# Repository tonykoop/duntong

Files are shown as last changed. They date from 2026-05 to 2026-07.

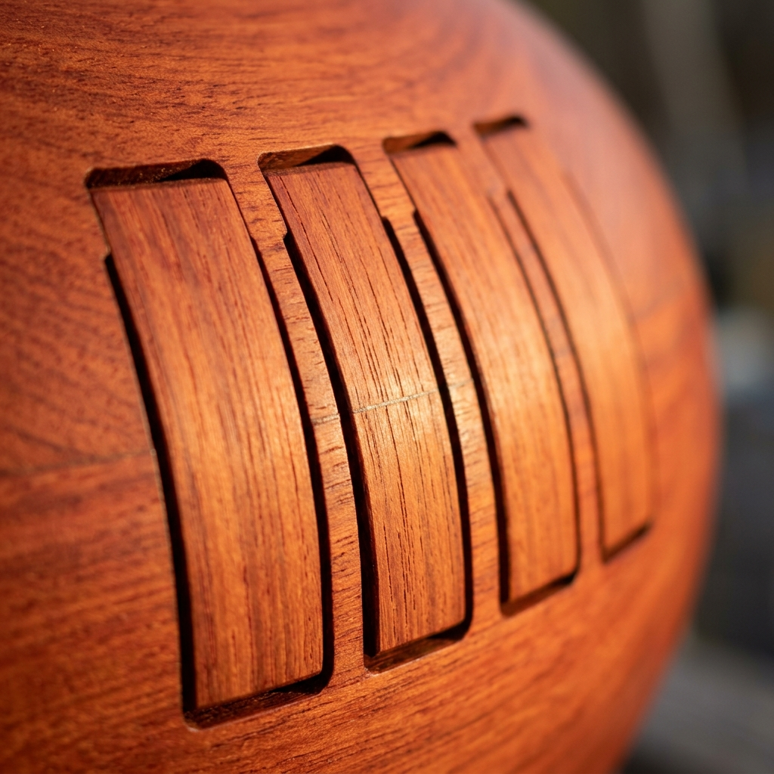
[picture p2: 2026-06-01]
images/macro/tongue-ring.png

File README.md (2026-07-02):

# Duntong - Original Cylindrical Tongue Drum

> Tony Koop's original hybrid instrument concept: a dundun-inspired cylindrical drum body with tuned wooden tongue-drum voices cut around the shell.

**Status:** L2 V5 build-packet candidate

## What This Is

The duntong is an original instrument design by Tony Koop. It combines the social, cylindrical playing form of a hand drum with the melodic tuning logic of a wooden tongue drum. Instead of cutting tongues into a flat box lid, the duntong places cantilever tongues around a round shell so the instrument can be played from multiple sides.

The current design table defines two prototype sizes:

1. **Handheld:** 6 in OD x 9 in long, C5-root pentatonic minor, 0.375 in tongue wall.
2. **Medium:** 12 in OD x 16 in long, C4-root pentatonic minor, 0.5 in tongue wall.

The V1 build target is the medium stave-cylinder prototype with a single ring of eight tongues around the equator. The workbook also preserves sealed, ported, and drumhead end variants so the instrument can be tested as a melodic tongue drum, a resonant ported body, and a true dundun/tongue hybrid.

## Why It Is Interesting

Most wooden tongue drums are rectangular boxes. Most dunduns are membrane drums. The duntong asks a neat acoustics question: can a round wooden drum body carry tuned cantilever tongues while still behaving like a hand-drum shell?

The current model treats the tongues as fixed-free cantilever beams:

```text
f = K * t / L^2
```

The cylinder cavity is treated as secondary coupling, not as the main pitch source. The first prototype should measure how much the curved wall, stave glue lines, end condition, and cavity resonance shift the tongue predictions.

## Repository Map

```text
duntong/
├── README.md
├── design.md
├── duntong-design-table.xlsx
├── family-spec.csv
├── bom.csv
├── sourcing.csv
├── cut-list.csv
├── validation.csv
├── assembly-manual.md
├── supplier-rfq.md
├── visual-bom-brief.md
├── drawing-brief.md
├── risks.md
├── photo-shotlist.md
├── cad/
├── cnc/
├── data/
├── drawings/
├── images/
├── site/
├── wolfram/
└── evolution/
```

## Current Status

L2 V5 build-packet candidate; not build-ready. The repo has
workbook-derived dimensions, a parametric OpenSCAD master-layout starter,
review SVG drawings, CNC planning notes, and print/capstone outputs. It does
not yet contain measured prototype data, SolidWorks-native CAD, DXF exports,
MCP-generated renders, or shop-validated CAM.

| Area | Status |
|---|---|
| Original concept and workbook | Done |
| Guided v4.2 intake | Done |
| Build packet docs | Drafted for V1 review; not build-ready |
| Drawings | SVG review drawings included; no DXF fabrication export yet |
| CNC/CAM | Pre-CAM operation plan only; no G-code |
| OpenSCAD | Parametric master-layout starter; not production CAM |
| SolidWorks | MasterLayout handoff files included; no native SolidWorks part yet |
| Visual authority | `visual-output-register.csv` records design-table/CAD authority and review-only previews |
| Explorer | Root `explorer.html` added for packet review |
| Wolfram | Readable `.wl` source included; source-only, not executed |
| Prototype data | Forthcoming |
| Evolution intake | Stage 0 intake complete (`evolution/`); Gate A not run |

## Authority And Unknowns

- Fabrication authority is limited to workbook/design-table-derived starter
  values in `duntong-design-table.xlsx`, `cad/design-table-inputs.csv`, and
  `cad/sw-global-variables.csv`.
- `cad/duntong_master.scad` is a parametric master-layout starter. It is useful
  for review, STL experiments, and downstream CAD translation, but it is not
  shop-validated production geometry.
- SVG files in `drawings/` are review previews. They do not replace a checked
  DXF, native CAD drawing, or measured template.
- Padauk material constants, curved-shell tongue behavior, end-condition
  coupling, drumhead hardware, D minor retuning, fixture clearances, feeds and
  speeds, and all prototype tuning data remain measurement-required.

## Sister Repos

- [tongue-drum](https://github.com/tonykoop/tongue-drum) for cantilever tongue physics and the DoE tuning pattern.
- [dundun](https://github.com/tonykoop/dundun) for the drum-family inspiration.
- [djembe](https://github.com/tonykoop/djembe) and [ashiko-drum-workshop](https://github.com/tonykoop/ashiko-drum-workshop) for segmented/stave drum construction references.

## License

[CC BY 4.0](LICENSE) - see LICENSE for details.

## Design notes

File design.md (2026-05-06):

# Duntong Build Design

## Project Intent

The duntong is Tony Koop's original cylindrical tongue drum concept. It combines a dundun-like round body and optional drumhead/ported ends with wooden tongue drum voices cut directly into the shell wall.

The first build should answer three practical questions:

1. Can a cylindrical stave shell hold predictable cantilever tongue pitches?
2. Which end configuration gives the best musical balance: sealed, ported, or drumheaded?
3. Can the V1 be manufactured safely with Tony's available home-shop and Maker Nexus workflows before SolidWorks CAM exists?

Mode A repo shape is used here: this is a single-instrument repository, so files live at the repo root and in conventional folders.

## Design Intake

| Field | Value |
|---|---|
| Instrument ID | DNT-001 |
| Instrument type | Duntong |
| Family | Cylindrical tongue drum / drum-skin hybrid |
| Inventor | Tony Koop, 2026 |
| Workbook | `duntong-design-table.xlsx`, sheet `Duntong` |
| Reference workbook | `Musical Instruments V2.xlsx`, sheet `Duntong` |
| Done-bar reference | `tonykoop/tongue-drum` for tongue physics; `tonykoop/djembe`, `tonykoop/conga`, and `tonykoop/ashiko-drum-workshop` for segmented/stave construction |
| V1 recommendation | Medium stave cylinder, single-ring tongue layout, sealed or goatskin end option |
| Current scale baseline | C minor pentatonic from the workbook |
| Alternate scale request | D minor pentatonic remains TBD until the workbook row is updated |
| Primary material | Padauk in the workbook; cherry or maple alternate TBD |

Guided intake outputs are in `data/design-intake.json` and `data/design-input-row.csv`.

## Governing Model

### Tongues

The primary pitch model is a fixed-free cantilever beam:

```text
f = K * t / L^2
L = sqrt(K * t / f)
```

Where:

- `f` is tongue fundamental frequency in Hz.
- `K` is the material-specific imperial cantilever constant from the tongue-drum material library.
- `t` is the shell wall thickness in inches. This is also the tongue thickness.
- `L` is tongue length in inches.

For the workbook baseline, `K = 24438` for Padauk. The model assumes the tongue behaves like a flat cantilever. The workbook flags curvature as acceptable when tongue width divided by cylinder OD is less than or equal to 0.20. The handheld ratio is 1.0 / 6.0 = 0.167. The medium ratio is 1.5 / 12.0 = 0.125. Both are inside the first-pass range, but the curved shell may still raise pitch by about 2-5 percent and must be measured.

### Body And End Coupling

The cylinder body is secondary coupling, not the main pitch source. Four end conditions are preserved as design variants:

| Option | End condition | First-pass model | Musical character |
|---|---|---|---|
| A | Both ends solid | Helmholtz-like cavity using tongue slits as neck openings | Warm, focused sustain |
| B | One port, one solid | Stopped pipe approximation | Deeper bass projection |
| C | Two ports | Open pipe approximation | Brighter projection |
| D | One or both drumheads | Membrane plus cantilever hybrid | Closest to dundun inspiration |

Important guard rule: the NAF K2 bore correction does not apply to this instrument. Only cantilever beam K constants are used for tongue pitch. Helmholtz/stopped/open-pipe equations are exploration and validation targets for the body, not corrections to tongue length.

### Worked Medium Example

For the medium prototype:

```text
OD = 12.000 in
length = 16.000 in
wall/tongue thickness = 0.500 in
tongue width = 1.500 in
slit width = 0.125 in
K = 24438
root MIDI = 60 (C4)
```

The C4 tongue prediction is:

```text
L = sqrt(24438 * 0.5 / 261.63) = 6.834 in
```

The medium shell circumference is `pi * 12 = 37.699 in`, allowing about 23 tongue-width-plus-slit slots. The requested 8 tongues fit.

Using the workbook formula for sealed-body slit-area coupling:

```text
slit area = 8 * (0.125 * 1.5 + 2 * 0.125 * 3.0) = 7.5 in^2
internal volume = pi * (11 / 2)^2 * 16 = 1520.5 in^3
effective neck length = 0.5 in
f_H = 13552 / (2*pi) * sqrt(7.5 / (1520.5 * 0.5)) = about 214 Hz
```

The workbook prose note also mentions 135 Hz for medium sealed coupling. That appears to be a stale or alternate-geometry note; keep it visible as a validation question rather than treating either value as proven.

## Family / Variant Targets

| Variant | OD (in) | Length (in) | Wall (in) | Root | Tongues | Construction target |
|---|---:|---:|---:|---|---:|---|
| DNT-HANDHELD | 6.000 | 9.000 | 0.375 | C5 | 8 | Split-blank or stave prototype |
| DNT-MEDIUM | 12.000 | 16.000 | 0.500 | C4 | 8 | V1 stave cylinder |

Medium predicted tongue table:

| # | Note | MIDI | Target Hz | Predicted L (in) |
|---:|---|---:|---:|---:|
| 1 | C4 | 60 | 261.63 | 6.834 |
| 2 | Eb4 | 63 | 311.13 | 6.267 |
| 3 | F4 | 65 | 349.23 | 5.915 |
| 4 | G4 | 67 | 392.00 | 5.583 |
| 5 | Ab4 | 68 | 415.30 | 5.424 |
| 6 | Bb4 | 70 | 466.16 | 5.120 |
| 7 | C5 | 72 | 523.25 | 4.832 |
| 8 | Eb5 | 75 | 622.25 | 4.431 |

## Hardware Alignment

The V1 build is a stave-cylinder shell with CNC-cut tongue slits. The CNC plan is pre-CAM only; feeds, speeds, hold-down, and simulation must be set at the actual machine.

| Operation | Tooling | Fixture / datum | Notes |
|---|---|---|---|
| Rip staves | Table saw, miter sled | Long edge datum, 15 deg miter for 12 staves | Cut extra staves for tuning and destructive tests |
| Thickness staves | Planer / drum sander | Outside face A | Tongue pitch depends directly on final wall thickness |
| Glue cylinder | Band clamps or hose clamps | Shell axis datum A | Glue in two half-shells, then join halves |
| True shell | Lathe | Shell axis between centers/chuck | Final wall is tuning-critical |
| End cap or drumhead prep | Lathe, band saw, drill press | End plane datum B/C | Preserve sealed, ported, and drumhead variants |
| Tongue layout | 1:1 wrap template or SolidWorks unwrap | Shell axis A, equator plane D, index zero E | Single ring around equator for V1 |
| Tongue cuts | CNC router, 1/8 in upcut spiral | V-block cradle, rotary indexing, shell axis A | Start tongues about 5 percent long/flat for tuning trim |
| Tuning | Files, Dremel, tuner | Tongue root and tip marks | Shorten tip to raise pitch; thin near base to lower pitch |

## SolidWorks MasterLayout Plan

Do not fake SolidWorks files. This repo includes a real handoff:

- `cad/SolidWorks-MasterLayout-Plan.md`
- `cad/design-table-inputs.csv`
- `cad/sw-global-variables.csv`

The MasterLayout should own shell OD/ID/length, wall thickness, stave count, miter angle, tongue count, tongue lengths, slit width, tongue band position, end cap variant, port diameter, trim allowance, and registration datums. It should also include an unwrap or wrap-template drawing for V1 CNC layout.

## Open Assumptions

| Assumption | Status | Test |
|---|---|---|
| Padauk K = 24438 applies to curved shell tongues | First-order only | Measure struck pitch before and after slit tuning |
| Curvature ratio below 0.20 keeps flat-beam formula usable | First-order only | Compare predicted vs measured cents error on all eight tongues |
| Medium sealed-body coupling is near 214 Hz by current formula | Formula result | Verify against Excel cached value and measured cavity tap/impulse response |
| Workbook prose note of 135 Hz body resonance is stale or alternate geometry | TBD | Recalculate in Excel and Wolfram after dimensions are frozen |
| Single-ring layout is playable by one or two players | TBD | Mock hand reach on a 12 in diameter cylinder before CNC |
| Goatskin end option is the "true duntong" expression | Design intent | Build sealed, ported, and goatskin variants for comparison |

## Validation Plan

1. Build a scrap tongue coupon at the same wall thickness and grain orientation.
2. Cut one reference C4 tongue 5 percent long and tune upward to target.
3. Record before/after frequency, humidity, temperature, and material thickness.
4. Build the medium shell and cut the eight tongues from longest to shortest.
5. Measure every tongue after rough cut, after tuning, and after finish.
6. Test sealed, one-port, and goatskin end configurations with the same tongue set where practical.
7. Update `validation.csv` and feed measured data back through the empirical-learning loop once a prototype exists.

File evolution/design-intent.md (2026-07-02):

# Design Intent — duntong rev A

- Master CAD: `cad/duntong_master.scad` (sha256: 723e69e6e639454bb9617963085709aae8129c8bf647d1cce9ca808ccdad349c), driven by `duntong-design-table.xlsx` (sha256: f86e424c1b98947c1ae340889d75ffa5f2e7d94e46fb72afa1dfbccc727afe02)
- Function: A cylindrical stave-shell drum body that carries tuned cantilever wooden tongues cut around its wall (V1 target: medium size, 12 in OD x 16 in long, single ring of eight tongues, C4-root pentatonic minor, sealed end baseline). The tongues are the primary pitch source (fixed-free cantilever, `f = K * t / L^2`, Padauk `K = 24438`); the cylinder cavity and end condition (sealed / one-port / two-port / drumhead) are secondary coupling under test. Handheld variant (6 in OD x 9 in long, C5-root) is preserved as a parametric alternate.
- Environment: hand-played percussion/melodic instrument; struck tongues carry cyclic fatigue load at stave glue lines; solid-wood shell and tongues move with humidity; optional goatskin head carries static rope-tension load.
- Target qty: 1 (prototype). Deadline: TBD. Budget/unit ceiling: TBD.

## Critical dimensions (carry tolerances)

| Feature | Nominal | Tolerance | Why critical | Source |
| --- | --- | --- | --- | --- |
| Shell OD (medium) | 12.000 in | scrap-coupon Hz check before shell cut | sets cavity coupling + tongue width/OD curvature ratio | design-table-inputs.csv row DNT-MEDIUM-SEALED |
| Wall thickness (= tongue thickness, medium) | 0.500 in | ±5% cents error tolerance (validation.csv) | directly sets tongue frequency via `f = K*t/L^2` | design-table-inputs.csv / validation.csv tolerance_cents=5 |
| Tongue length per note (medium, e.g. C4) | 6.834 in (predicted) | measured vs. target Hz, 5 cents tolerance | intonation | validation.csv V-001, cantilever formula |
| Tongue width | 1.500 in (medium) / 1.000 in (handheld) | width/OD ≤ 0.20 (curvature validity limit) | keeps flat-cantilever model valid; curved shell may still shift pitch 2-5% (measurement-required) | design.md Governing Model |
| Stave count / miter angle | 12 staves, 15.000 deg miter | glue-line placement vs. tongue centerlines | tongue must not cross a glue line (risks.md, High severity) | cad/design-table-inputs.csv |
| Root note (medium) | MIDI 60 (C4) | design-table row change required to alter | sets whole pentatonic layout | design-table-inputs.csv root_midi |
| Body cavity response (sealed, medium) | 214.23 Hz (first-pass) | ±20 cents tolerance, verify vs. Excel + impulse response | secondary coupling could shift measured tongue Hz | validation.csv V-009 |
| Port diameter (ported variant) | 3.000 in | measurement-required if Config B/C built | stopped/open-pipe body tuning | design-table-inputs.csv port_diameter_in |

## Incidental (free for DFM)

- End-cap cosmetic profile, stave grain/figure selection (beyond stated material), rubber-foot/cradle-stand styling, finish sheen, note-position labeling/inlay.

## Must-nots (DFM may never violate)

- Tongue centerlines must not cross stave glue lines without a validated split-blank or wider non-vibrating bridge (risks.md, Structural, Severity: High — human decision required before cutting).
- Do not substitute tonewood species without updating the workbook `K` constant and cutting a validated coupon first (risks.md, Supply).
- Do not finish tuned tongues with the standard schedule before measuring before/after Hz and damping on a coupon (risks.md, Fit/Finish).
- Tongue width/OD ratio must stay ≤ 0.20 (design.md validity boundary) or the flat-cantilever model is no longer applicable without a re-derived curved-shell correction.

## Material intent

- Preferred: Padauk staves and end caps (or matching hardwood) per bom.csv B-001/B-002; goatskin/calfskin head optional for the drumhead-hybrid end variant (B-004).
- Acceptable subs: cherry or hard maple for body/tongues if the workbook `K` constant is updated first (bom.csv substitute_rule); synthetic head as an alternate to goatskin.
- Forbidden: none recorded.

## Stage status

Stage 0 intake complete 2026-07-01. Gate A (Alpha shop compile) NOT yet run — no concessions logged, nothing presented as shippable.

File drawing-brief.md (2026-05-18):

# Drawing Brief

## Drawing Set

The current SVG drawing set is review-grade and should be replaced or extended by SolidWorks drawings before cutting expensive stock.
Visual authority for the current packet is tracked in
`visual-output-register.csv`. The existing SVG files are derived review
previews, not DXF/CAD fabrication authority.

| Drawing | Purpose |
|---|---|
| `drawings/body-overview.svg` | Overall medium and handheld envelopes, major datums, V1 build target |
| `drawings/tongue-layout.svg` | Single-ring tongue schedule, note order, tongue lengths, wrap-template concept |
| `drawings/end-config-options.svg` | Sealed, ported, open/open, and drumhead end variants |
| `drawings/section-view.svg` | Cross-section of stave shell, wall/tongue thickness, end cap, V-block fixture concept |

## Drawing Standards

Each drawing must preserve:

- Title block with instrument, part, units, revision, date, and source workbook.
- Datums: shell axis A, left end B, right end C, equator plane D, index zero E.
- Critical dimensions: OD, ID, length, wall/tongue thickness, tongue length, tongue width, slit width, port diameter, and end cap rabbet.
- Default tolerance block: +/- 0.005 in for tongue length/thickness, +/- 0.030 in for noncritical wood body features unless CAD says otherwise.
- Material notes: Padauk baseline, alternate species require K update.
- Operation notes: no G-code; V-block or rotary indexing required for cylindrical tongue cuts.

## CAD Handoff

SolidWorks should create:

1. MasterLayout part with global variables from `cad/sw-global-variables.csv`.
2. Configuration table for handheld and medium variants.
3. Cylindrical unwrap sketch for the single-ring tongue layout.
4. Optional end-cap configurations: sealed, ported, drumhead.
5. Drawing sheets exported to PDF/SVG before CAM.

## Missing V5 Visual Gates

- Export checked DXF plates from native CAD or an Illustrator-reviewed vector
  master before marking the drawing set shop-ready.
- Replace review SVG previews with derived previews that name the governing
  CAD/DXF/design-table source.
- Add Blender/Photoshop/image-generation outputs only after logging their
  source artifacts and keeping them concept/support-only unless derived from
  fabrication authority.

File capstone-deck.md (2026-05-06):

# Duntong Original Cylindrical Tongue Drum
- Musical instrument documentation capstone
- Build packet: duntong
- Generated: 2026-05-05

---

# Project Intent
- The duntong is Tony Koop's original cylindrical tongue drum concept. It combines a dundun-like round body and optional drumhead/ported ends with wooden tongue drum voices cut directly into the shell wall.

_Speaker notes:_ Read design.md before committing to dimensions or sourcing decisions.

---

# Physics Model
- ### Tongues

```
f = K * t / L^2
L = sqrt(K * t / f)
```

```
OD = 12.000 in
length = 16.000 in
wall/tongue thickness = 0.500 in
tongue width = 1.500 in
slit width = 0.125 in
K = 24438
root MIDI = 60 (C4)
```

```
L = sqrt(24438 * 0.5 / 261.63) = 6.834 in
```

```
slit area = 8 * (0.125 * 1.5 + 2 * 0.125 * 3.0) = 7.5 in^2
internal volume = pi * (11 / 2)^2 * 16 = 1520.5 in^3
effective neck length = 0.5 in
f_H = 13552 / (2*pi) * sqrt(7.5 / (1520.5 * 0.5)) = about 214 Hz
```

_Speaker notes:_ Governing equations extracted verbatim from design.md. Apply empirical corrections (NAF K2, scale offsets) only where the model permits — see references/acoustic-models.md.

---

# Hardware Alignment
- The V1 build is a stave-cylinder shell with CNC-cut tongue slits. The CNC plan is pre-CAM only; feeds, speeds, hold-down, and simulation must be set at the actual machine.

| Operation | Tooling | Fixture / datum | Notes |
| --- | --- | --- | --- |
| Rip staves | Table saw, miter sled | Long edge datum, 15 deg miter for 12 staves | Cut extra staves for tuning and destructive tests |
| Thickness staves | Planer / drum sander | Outside face A | Tongue pitch depends directly on final wall thickness |
| Glue cylinder | Band clamps or hose clamps | Shell axis datum A | Glue in two half-shells, then join halves |
| True shell | Lathe | Shell axis between centers/chuck | Final wall is tuning-critical |
| End cap or drumhead prep | Lathe, band saw, drill press | End plane datum B/C | Preserve sealed, ported, and drumhead variants |
| Tongue layout | 1:1 wrap template or SolidWorks unwrap | Shell axis A, equator plane D, index zero E | Single ring around equator for V1 |
| Tongue cuts | CNC router, 1/8 in upcut spiral | V-block cradle, rotary indexing, shell axis A | Start tongues about 5 percent long/flat for tuning trim |
| Tuning | Files, Dremel, tuner | Tongue root and tip marks | Shorten tip to raise pitch; thin near base to lower pitch |

_Speaker notes:_ Identifies which shop pipeline(s) this instrument lives in: Bambu+kiln slip-cast, 40W laser flat-pack, CNC+lathe, segmented turning, drum-skin work, or hybrid combinations.

---

# How To Use This Packet
- Start with design.md for intent and assumptions.
- Use bom.csv, sourcing.csv, and cut-list.csv before buying or cutting.
- Use drawing-brief.md and CAD/CNC folders before machining.
- Print the packet for shopping, shop work, and validation.

---

# File Map
- design.md: Project intent, catalog metadata, assumptions, and validation plan.
- bom.csv: Starter bill of materials with part categories, quantities, drawing refs, and notes.
- sourcing.csv: Supplier/search tracker with specs, price/date fields, lead time, substitutes, and risks.
- cut-list.csv: Rough/final stock sizes, material, grain/orientation, operations, yield, and offcuts.
- drawing-brief.md: Manufacturing drawing and technical product sketch brief.
- assembly-manual.md: Shop-facing sequence, tools, fixtures, safety, tuning, finishing, and maintenance notes.
- validation.csv: Target/measured values, tolerance, environment, result, and tuning/build action log.
- supplier-rfq.md: Supplier email/request-for-quote starter.

---

# Family Spec

| member_id | target_hz | target_note | scale_label | predicted_length_in | predicted_width_in | predicted_height_in | predicted_volume_cuin | wood_species | k_constant | k2_correction | outer_diameter_in | inner_diameter_in | wall_thickness_in | tongue_count | slit_width_in | construction_method | notes |
| --- | --- | --- | --- | --- | --- | --- | --- | --- | --- | --- | --- | --- | --- | --- | --- | --- | --- |
| DNT-HANDHELD | 523.25 | C5 | C minor pentatonic | 9.000 | 6.000 | 6.000 | 194.83 | Padauk | 24438 | 0 | 6.000 | 5.250 | 0.375 | 8 | 0.125 | split-blank or stave | Handheld proof of concept; workbook root MIDI 72 |
| DNT-MEDIUM | 261.63 | C4 | C minor pentatonic | 16.000 | 12.000 | 12.000 | 1520.53 | Padauk | 24438 | 0 | 12.000 | 11.000 | 0.500 | 8 | 0.125 | stave cylinder | V1 build target; medium floor/table instrument |

_Speaker notes:_ Sizes scale via the master scale factor; tuning targets are first-order Helmholtz/cantilever predictions to be empirically corrected per prototype.

---

# Build Workflow
- Design and assumptions
- Source materials and hardware
- Prepare stock, fixtures, and CNC/laser/lathe setup
- Assemble, tune, finish, and validate

---

# Sourcing And BOM
- BOM gives part categories and drawing references.
- Sourcing tracks search terms, supplier candidates, price/date, lead time, substitutions.
- Visual BOM brief turns the parts list into a presentation-ready image board.

---

# Shop Packet
- Cut list for lumber/sheet/blank planning.
- Assembly manual for away-from-keyboard work.
- Validation sheet for measured dimensions, tuning, pass/fail checks.

---

# Drawings, CAD, CNC
- drawing-brief.md defines required views, dimensions, datums, sketch intent.
- cad/ holds models and design tables.
- cnc/ holds CAM, toolpaths, setup sheets, dry-run notes.
- drawings/ holds PDFs, SVGs, DXFs, drawing exports.






---

# Images And Screenshots
- Add hero render/photo, visual BOM, shop screenshots, drawing previews, validation photos in images/.

---

# Validation Plan
- A4 = 440 Hz reference check.
- Tuning targets logged in validation.csv.
- Critical dimensions verified against design sheet and CAD.
- Photos and revision notes after each major step.

---

# Open Risks / Decisions
- TBDs in design sheet and BOM.
- Supplier price/availability not yet verified.
- Generated images marked as concept placeholders.
- Empirical corrections await measured prototype data.

---

# Next Actions
- Replace TBDs with measured/source-backed values.
- Verify live supplier price and availability before buying.
- Export final drawings and visual BOM images.
- Regenerate this deck and print packet after final edits.

---

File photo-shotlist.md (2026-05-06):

# Photo Shotlist

This follows `instrument-maker/docs/photo-pipeline.md`. No owned duntong hero photo exists yet, so the README and site should say photos forthcoming rather than link broken images.

## File Naming

Use:

```text
images/00-hero-duntong-medium-finished.jpg
images/01-workbook-design-table.jpg
images/02-stave-stock-layout.jpg
images/03-stave-glue-up.jpg
images/04-turned-cylinder-shell.jpg
images/05-wrap-template-on-shell.jpg
images/06-vblock-cnc-setup.jpg
images/07-tongue-slit-cutting.jpg
images/08-tuning-with-tuner.jpg
images/09-end-config-comparison.jpg
images/10-finished-detail.jpg
```

## Required Shots

| Shot | Purpose | Status |
|---|---|---|
| Hero finished instrument | README/site hero | Forthcoming |
| Workbook/source table | Shows parametric design source | Forthcoming |
| Stave stock | Documents grain and material | Forthcoming |
| Stave glue-up | Shows cylindrical shell construction | Forthcoming |
| Lathe turning | Shows wall thickness control | Forthcoming |
| Wrap template | Shows cylindrical tongue layout | Forthcoming |
| V-block CNC setup | Shows safe workholding | Forthcoming |
| Tongue cutting | Shows slit operation | Forthcoming |
| Tuning | Shows validation method | Forthcoming |
| End variants | Sealed/ported/drumheaded comparison | Forthcoming |

## Rules

- Use owned photos when available.
- If generated concept images are added, label them as generated placeholders.
- Replace generated or drawing placeholders with process photos after the first prototype.
- Do not use absolute local paths in README or `site/index.html`.

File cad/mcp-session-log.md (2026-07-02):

# MCP Session Log - Duntong

Current status: no MCP sessions were run in this Round 30 conservative lane.
This log is present so future V5 work can record OpenSCAD, Blender,
Illustrator, Photoshop, image-generation, or other MCP-generated artifacts
without inventing provenance for the existing packet.

| timestamp_utc | tool | session_id | artifact | parent_artifact | authority | notes |
|---|---|---|---|---|---|---|
| 2026-05-18 | none | n/a | cad/duntong_master.scad | cad/design-table-inputs.csv | starter_layout | Existing OpenSCAD starter reviewed as packet evidence; no live MCP session used in this lane. |
| 2026-05-18 | none | n/a | drawings/*.svg | cad/design-table-inputs.csv | derived_preview | Existing SVGs are review previews and are tracked in visual-output-register.csv. |
| 2026-07-01 | claude-code (Fable 5) + OpenSCAD CLI | fable-v5-refresh-2026-07-01 | cad/duntong_master.scad | cad/design-table-inputs.csv | pending_measurement | V5 packet refresh: existing parametric master kept as-is (EXISTING MASTERS clause; not rewritten). Render check: `openscad -o /tmp/duntong-check.stl cad/duntong_master.scad`, exit 0. |
| 2026-07-01 | claude-code (Fable 5) | fable-v5-refresh-2026-07-01 | wolfram/duntong-wolfram-model.wl | cad/design-table-inputs.csv | derived_preview | Existing Wolfram cantilever/cavity model source reviewed for V5 register; source-only, not executed (wolframscript not run per V5 evidence rule). |
| 2026-07-01 | claude-code (Fable 5) | fable-v5-refresh-2026-07-01 | bom.csv, sourcing.csv, cut-list.csv, validation.csv, cad/design-table-inputs.csv | duntong-design-table.xlsx | fabrication | V5 refresh pass: tabular packet data reviewed against design-table baseline; no dimension changes made. Provenance row added to satisfy V5 fabrication-artifact logging. |

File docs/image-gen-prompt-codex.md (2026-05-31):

# Duntong Image-Gen Prompts

Concept visualization only; not fabrication authority. Do not infer tongue
lengths, shell thickness, port size, head hardware, or tuning from these
prompts.

## Hero Prompt

Photorealistic 3/4 product photograph of the Duntong, Tony Koop's original cylindrical tongue-drum concept: a medium stave-built round wooden cylinder with a single ring of eight tuned tongue shapes cut around the equator, warm Padauk, cherry, or maple wood, smooth turned ends, and an optional sealed end, ported end, or goatskin drumhead variant visible at one side. The instrument should read as a dundun-inspired body crossed with a wooden tongue drum, playable from multiple sides, with soft mallets nearby for scale. Clean studio background, soft directional lighting, 50mm lens, high detail, photorealistic.

## In-Context Prompt

Photorealistic workshop scene of the Duntong prototype being tested on a bench cradle: a player uses soft mallets to strike the tongue ring around the cylinder while another end configuration, wrap template, tuner, and CNC V-block cradle sit nearby. Natural shop light, visible stave construction, believable hand reach around the shell, and an exploratory original-instrument mood.

## Detail / Macro Prompt

Photorealistic macro close-up of the Duntong tongue band: curved-shell wooden cantilever tongues cut cleanly around a cylindrical stave body, fine slit kerfs, visible equator layout marks removed or faint, and a smooth satin finish showing grain direction across each tongue. Show the shell curvature and tongue relief clearly, with a soft mallet head entering the edge of frame. High-detail macro, shallow depth of field.

## Negative / Avoid

No text, logos, watermarks, flat box tongue drum, impossible curved slits, fake note labels, extra limbs, distorted hands, or cutaway dimensions.

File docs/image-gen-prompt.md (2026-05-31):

# Image-Gen Prompts

Concept image only; not fabrication authority. Do not include cut-ready dimensions, hole locations, or toolpaths.

## Hero Prompt

A single finished "duntong," an original cylindrical wooden tongue drum standing upright like a short barrel: a tall round drum body built from many narrow vertical Padauk staves glued into a seamless cylinder, the wood a warm reddish-orange with subtle vertical grain lines marking the stave seams, satin oil finish catching the light. Around the middle of the cylinder, encircling it like a belt, runs a single ring of eight slender wooden tongues cut directly into the curved shell wall — each tongue a long narrow rectangular cutout, fixed at one end and free at the tip, the tongues stepping shorter in sequence around the circumference to suggest a tuned melodic scale, thin dark slit gaps outlining each tongue against the body. The top end shows a recessed solid wooden end cap; the form reads as a hand-drum shell that has been turned smooth and true on a lathe. Realistic table-height scale, roughly a foot in diameter. Clean neutral studio background, soft directional studio light raking across the curved staves to show the cylinder's roundness and the relief of the cut tongues, 3/4 product-photography angle, ~50mm lens, high detail, photorealistic, no text labels.

## In-Context Prompt

Two duntong drums staged together on a warm wooden workshop bench near a window — the larger medium floor-size cylinder standing on the bench and the smaller handheld version resting beside it, both turned from reddish-orange Padauk staves with the signature ring of eight cut tongues around each shell equator. A pair of soft felt-tipped mallets and a few wood shavings rest nearby, hinting at a recently completed build. Natural side light from the window, shallow depth of field with the smaller drum softly out of focus, environmental storytelling of a maker's shop, concept visualization only, photorealistic, no text labels.

## Detail Prompt

Macro close-up of the signature tongue ring on the curved Padauk shell: three or four adjacent cantilever tongues cut into the rounded wall, each a long slender rectangle anchored at its base and free at the tip, separated from the body by a clean narrow dark slit that wraps slightly with the cylinder's curvature. Show the fine vertical grain of the reddish-orange wood, the faint glue seams between staves crossing the tongues, the crisp routed edges of the slits, and the satin sheen of an oil finish. Raking low-angle light emphasizes the slight relief of each tongue and the depth of the cut gaps. High detail, photorealistic, no measurements, no callouts.

## Negative / Avoid

No text/logos/watermarks/fake maker marks, no dimension callouts or measurement lines, no impossible mechanisms, no flat rectangular box tongue-drum lid (tongues must wrap a round shell), no metal hardware on the tongues; anatomically plausible hands if a player is shown.

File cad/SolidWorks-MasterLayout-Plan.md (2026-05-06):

# SolidWorks MasterLayout Plan - Duntong

## Purpose

This is the CAD handoff for the original duntong. It does not claim that a SolidWorks part exists. It defines the MasterLayout variables, configurations, datums, and drawings that should be created before CAM.

## MasterLayout Part

Create `DNT-001_MasterLayout.SLDPRT` with these top-level datums:

| Datum | Meaning | Use |
|---|---|---|
| A | Shell axis | Lathe, V-block, rotary indexing, section view |
| B | Left end plane | End cap and drumhead interface |
| C | Right end plane | End cap and drumhead interface |
| D | Tongue equator plane | Single-ring layout center |
| E | Index zero radial plane | First tongue centerline |

## Configurations

| Configuration | Purpose |
|---|---|
| DNT-HANDHELD | 6 in OD x 9 in long concept proof |
| DNT-MEDIUM-SEALED | V1 medium with solid end caps |
| DNT-MEDIUM-PORTED | Medium with one 3 in acoustic port |
| DNT-MEDIUM-DRUMHEAD | Medium with drumhead rim and hardware placeholder |

## Required Sketches

1. `SK_MasterEnvelope`: cylinder OD, ID, length, wall.
2. `SK_StaveSection`: 12-stave polygon, miter angle, glue line locations.
3. `SK_TongueUnwrap`: 37.699 in circumference x 16 in length flattened layout.
4. `SK_TongueRing`: eight tongue centerlines around equator.
5. `SK_EndOptions`: sealed cap, port cap, drumhead bearing edge.
6. `SK_VBlockFixture`: 12 in OD shell cradle and clamp clearance.

## Drawing Sheets

| Sheet | Contents |
|---|---|
| SHT-001 Body Overview | OD, ID, length, wall, datums, stave count |
| SHT-002 Tongue Layout | Unwrapped tongue paths, note labels, trim allowance |
| SHT-003 End Options | Sealed, ported, two-port, drumhead variants |
| SHT-004 CNC Setup | V-block, clamp zones, index rotation table |
| SHT-005 Validation | Measurement points, tuner logging callouts |

## CAD Rules

- Keep all driven dimensions named with the same variables used in `cad/sw-global-variables.csv`.
- Tongue lengths should be model dimensions, not sketch-only notes.
- Show stave seam locations relative to tongue roots before approving the CNC layout.
- Add suppressible features for the port and drumhead options rather than separate unrelated parts.
- Do not export CAM until the V-block fixture and clamp clearance are reviewed.

## Open Decisions

- Final V1 end condition: sealed, ported, or drumhead.
- Whether to rotate the tongue layout to avoid all glue-line crossings.
- Whether D minor pentatonic should replace the workbook's current C minor pentatonic baseline.
- Whether the first physical prototype should be medium stave or handheld split-blank.

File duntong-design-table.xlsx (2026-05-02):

Duntong — Cylindrical Tongue Drum (Original Design) |  |  | 2026-05-01
Cantilever tongues around a cylinder body · Sealed / Ported / Drum-headed end options · Segmented / Stave / Split-blank construction
Inventor: Tony Koop, 2026 · Physics: cantilever beam f = K × t / L² + Helmholtz resonator coupling
DESIGN INPUTS
Size Variant | Handheld | Medium | Notes
Cylinder Outer Ø (in) | 6.0 | 12.0 | Handheld fits in lap; Medium sits on floor/table
Cylinder Length (in) | 9.0 | 16.0 | Overall length including end caps
Wall Thickness (in) | 0.375 | 0.500 | ← This IS the tongue thickness (t in f = K×t/L²)
Tongue Width (in) | 1.0 | 1.5 | Width affects volume + sustain, NOT pitch
Slit Width (in) | 0.125 | 0.125 | 1/8" kerf from upcut spiral bit
Wood Species | Padauk | Padauk | K = 24,438 (cantilever). See material table below.
K (cantilever, imperial) | 24438 | 24438 | From Tongue Drum material library
Scale | Pentatonic Minor | Pentatonic Minor | 8 notes: root + offsets (+3,+5,+7,+8,+10,+12,+15)
Root Note (MIDI) | 72 | 60 | 72 = C5 (handheld); 60 = C4 (medium)
Number of Tongues | 8 | 8 | 8 tongues = pentatonic + octave. Max limited by circumference.
Speed of Sound (in/s) | 13552 | 13552 | At 68°F
END CONFIGURATION | End A (Left) | End B (Right)
Config Option | Solid wood | Solid wood | Options: "Solid wood" / "Acoustic port" / "Goatskin" / "Synthetic head"
Port Ø (if ported, in) | 2.0 | 3.0 | Only applies if "Acoustic port" selected above
TONGUE PHYSICS — Cantilever Beam on Cylinder Wall
f = K × t / L² — same cantilever formula as flat tongue drum. Curvature negligible when tongue_width << cylinder_Ø.
Curvature adds slight stiffening (~2-5% higher pitch vs flat). Empirical correction needed from prototype testing.
 | Handheld | Medium | Formula / Notes
Cylinder Inner Ø (in) |  |  | = outer_Ø − 2 × wall
Internal Volume (in³) |  |  | = π × (ID/2)² × length
Circumference (in) |  |  | = π × Ø (outer)
Max Tongues (fit check) |  |  | = circumference / (tongue_width + slit_width). Practical max.
Fit OK? |  |  | Requested tongues ≤ max available slots
Arc per Tongue (°) |  |  | = 360 / num_tongues
Curvature Ratio (tongue_W / Ø) |  |  | ≤ 20% → curvature effect negligible; > 20% → need empirical correction
Curvature Note |  |  | If >20%, tongues may ring ~2-5% sharp vs flat-surface prediction
CYLINDER RESONANCE — 4 End Configurations
Config | Model | Resonant Freq (Hz) | Character | Best For
A. Both ends solid | Helmholtz — tongue slits = neck opening |  | Warm, focused, sustaining — resonance reinforces tongues | Melodic tongue playing, meditation, ensemble
B. One port + one solid | Stopped pipe: f = c/(4×L) |  | Deep bass projection from port; tongues add melody on top | Bass-heavy, rhythmic, outdoor
C. Two ports (both open) | Open pipe: f = c/(2×L) |  | Brightest body resonance; less bass than B | Bright acoustic projection
D. One/both drumheads | Membrane + cantilever hybrid |  | Percussive attack from head + pitched tongues — true hybrid drum | Rhythm + melody; closest to dundun concept
Resonance Calculations (Medium size shown)
Config A — Helmholtz (sealed)
Total slit area (in²)
Effective neck length (in) |  |  | = wall thickness (sound passes through wall at slit)
Helmholtz freq (Hz) |  |  | f = (c/2π) × √(A_slit / (V_chamber × L_neck))
Coupling range (±20%) |  |  | Tongues within this freq range will couple strongly with body
Config B — Stopped Pipe (one port)
Pipe resonance (Hz) |  |  | f = c / (4 × L). Deep fundamental.
2nd harmonic (Hz) |  |  | Odd harmonics only (3×, 5×) — hollow character
Config C — Open Pipe (two ports)
Pipe resonance (Hz) |  |  | f = c / (2 × L). One octave above stopped.
2nd harmonic (Hz) |  |  | All harmonics present (2×, 3×, 4×) — brighter
TONGUE LAYOUT OPTIONS
Layout | Description | Pros | Cons | CNC Notes
1. Single Ring | All tongues in one row around the equator (midpoint of cylinder). Scale arranged L→R or alternating (like standard tongue drum). | Simplest to CNC (single Z-height). Easy to play flat or tilted. Natural hand position. | Limited to notes that fit in circumference. All tongues same thickness. | Single wrap-around toolpath. Index cylinder on rotary axis or use V-block jig + rotate.
2. Spiral | Tongues wrap helically up the cylinder. Scale ascends as you rotate — like a spiral staircase of pitches. | More tongues fit (uses full cylinder length). Visual showpiece. Scale flows naturally. | Harder to CNC (compound toolpath). Playing position less intuitive. | Needs 4th-axis rotary OR flatten-and-mark approach. SolidWorks unwrap for layout.
3. Multi-Band | 2-3 parallel rows of tongues at different heights. Each band could be a different octave or scale mode. | Most notes possible. Can separate registers (bass ring, treble ring). Educational — visible octave relationship. | Structurally weaker (many slits close together). Tongues between bands need reinforcement. | Multiple pass toolpaths at different Z-heights. Ribs between bands must be ≥1".
4. Staggered | Two offset rows where tongues interleave (like brickwork). Bass tongues longer, treble shorter — naturally accommodates length variation. | Efficient use of surface area. Long bass tongues span between short treble tongues. Balanced look. | Complex CNC layout. Some structural considerations at tongue intersections. | Careful CAD layout needed. Each tongue individually positioned. Best modeled in SolidWorks.
CYLINDER CONSTRUCTION METHODS
Method | Description | Pros | Cons | Best For
1. Segmented (Ring-Stack) | Stack glued rings on lathe, same as Ashiko/Conga. Straight cylinder (no taper). Miter angle = 180/segments_per_ring. | Decorative multi-wood patterns. Precise wall thickness from lathe. Proven technique (Tony has done 2 drums). | Many cuts (e.g. 12 rings × 12 seg = 144 pcs). Slower. Requires lathe swing ≥ Ø. | Medium size (12" fits on lathe). Showpiece instruments. Controlled wall uniformity.
2. Stave (Vertical) | Vertical staves glued edge-to-edge like a barrel. Same as Kora stave bowl option but cylindrical — straight taper = 0. | Fast (12-16 pcs vs 144). Continuous grain along tongues — best for tone. Strong. | Less decorative than segmented. Needs accurate miter angle on table saw. | Best tonal quality (grain runs along tongue length). Quick builds. Both sizes.
3. Split-Blank (Rip + Route) | Rip solid turning blank in half, CNC-route cylindrical bore in each half, re-glue. Same as Didgeridoo method. | Simplest construction. No segmenting or staving. Uniform grain. | Limited to Ø ≤ turning blank size (~6-8" max). Wasteful — most wood becomes chips. | Handheld size only. Quick prototype. Proof-of-concept builds.
Segmented Ring Parameters
Segments per Ring | 12
Number of Rings | 12 | ← For Medium. Handheld: ~8 rings.
Miter Angle (°)
Total Pieces
Ring Thickness (in) |  |  | = cylinder_length / num_rings
S.E.L. (in) |  |  | = π × outer_Ø / segments_per_ring
Stave Parameters
Number of Staves | 12
Stave Miter Angle (°)
Stave Width (in)
Stave Length (in)
Stave Thickness (in)
TONGUE DIMENSIONS — Pentatonic Minor (8 tongues, both sizes)
# | Offset | Note | MIDI | Freq (Hz) | Handheld L (in) | Medium L (in) | Fits Cylinder? | Hand Arc (°) | Med Arc (°)
1 | Root | C
2 | 3 | Eb
3 | 5 | F
4 | 7 | G
5 | 8 | Ab
6 | 10 | Bb
7 | 12 | C
8 | 15 | Eb
BILL OF MATERIALS (Stave construction, Medium, sealed ends)
# | Category | Item | Qty | Size / Notes
1 | Body | Staves (or segment blanks) |  | 16" × 3.1" × 1.0" each (Padauk). ~8 bd ft total.
2 | Body | End cap blanks (or drumheads) | 2 | 13" × 13" × 3/4" (if solid wood). Disc cut from plate or face-glued.
3 | Body | Acoustic port tube (if ported) | 1 | PVC or wood tube, 3" Ø × 1" length (= wall thickness)
4 | Head (opt) | Goatskin rawhide (if drum-headed) | 2026-01-02 | 16"+ diameter. Rope-tuned — need rope + tension rings.
5 | Head (opt) | Synthetic head + hardware (if hardware-tuned) | 2026-01-02 | 12" Remo or Evans. Need lugs, rods, hoops, bearing edge.
6 | CNC | 1/8" upcut spiral bit | 1 | For tongue slit cutting. 0.125" kerf.
7 | Hardware | Rubber feet / stand | 4 | Floor/table bumpers or custom cradle stand
8 | Consumables | Glue + sandpaper + finish | 1 | Titebond III, 80-400 grit, tung oil or lacquer
BUILD METHOD
Step | Phase | Operation | Tool | Notes
1 | Stock Prep | Rip staves on table saw at miter angle (15° for 12 staves) | Table saw, miter sled | Same technique as Kora stave bowl. Straight taper = 0 (no bowl curve).
2 | Stock Prep | Joint/plane staves to uniform thickness | Jointer, planer | Critical: tongue pitch depends on wall thickness. ±0.005" tolerance.
3 | Glue-Up | Glue staves into cylinder using band clamps or hose clamps | Clamps, glue | Two halves approach: glue 6+6, then join halves. Check round with calipers.
4 | Turning | Mount on lathe, true exterior to final Ø, bore interior to wall thickness | Lathe, bowl gouge | Final wall = tongue thickness. Measure frequently with calipers.
5 | End Caps | Turn/cut end discs from plate; glue into cylinder bore (or prep drum hardware) | Lathe or band saw | Rabbet joint: disc sits in a 1/4" recess inside cylinder. Sealed = glue. Port = drill before glue.
6 | Layout | Mark tongue positions on cylinder surface using SolidWorks unwrap template | Laser template | Print 1:1 scale wrap template. Tape around cylinder. Mark slit lines through template.
7 | CNC Slits | Cut U-shaped tongue slits with 1/8" upcut spiral | ShopBot CNC | V-block jig on CNC bed. Cut one tongue, rotate, repeat. Or rotary 4th axis if available.
8 | CNC Slits | Alternative: hand-cut slits with oscillating multi-tool or scroll saw | Multi-tool | Mark and cut carefully. Slower but no jig needed. Good for first prototype.
9 | Tuning | Tune each tongue: shorten tip to raise pitch, thin base to lower pitch | Dremel, file | Start with tongues ~5% long (pitch flat). Remove material from tip to tune sharp.
10 | Tuning | Verify all 8 tongues with chromatic tuner; iterate until within ±5 cents | Tuner | Same DoE tuning protocol as flat tongue drums. Record actual vs predicted.
11 | Head (opt) | Install drumhead: goatskin (soak+stretch+rope) or synthetic (hardware mount) | Rope or hardware | Bearing edge must be smooth and level. Goatskin: ≥ 24h soak. Synthetic: standard drum hardware.
12 | Finishing | Sand 80→400, apply 2-3 coats tung oil or lacquer | Sandpaper, oil | Avoid finish on tongue surfaces if possible — it can dampen vibration slightly.
13 | Finishing | Add rubber feet or build cradle stand for floor placement | Hand | Cylinder needs support to not roll. Cradle stand or 3-point feet.
DESIGN NOTES
1. ORIGINAL INSTRUMENT DESIGN by Tony Koop (2026). No known prior art for a cylindrical tongue drum with circumferential slit tongues.
2. Curvature effect: At <20% width/Ø ratio, flat cantilever formula is a good first approximation. Build a prototype and measure actual vs predicted.
3. Helmholtz coupling (Config A, sealed): the body resonance (135 Hz for Medium) is below the lowest tongue (523 Hz). This means the body adds warmth but won't couple tightly. For coupling, use a lower root (e.g., C3 MIDI 48) or a smaller sealed volume.
4. Config D (drumhead) is the true Duntong — closest to the dundun inspiration. Goatskin rope-tuned gives the most organic, West African character.
5. Tongue layout recommendation for V1 prototype: Single Ring around equator. Simplest to build, easiest to play, proves the concept.
6. The cylinder shape gives 360° of playing surface — two players can sit opposite each other and play simultaneously. Social instrument.
7. Stave construction recommended for V1: continuous grain along tongue = best sustain and tone. Segmented is a V2 showpiece option.
8. CNC jig: V-block cradle clamped to ShopBot bed. Router approaches from above for each slit. Rotate cylinder between tongues.
9. Potential enhancement: different wall thicknesses per tongue zone (thicker = lower K, thinner = higher). Would need CNC interior profiling.
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

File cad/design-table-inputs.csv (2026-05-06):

configuration | shell_outer_diameter_in | shell_length_in | wall_thickness_in | inner_diameter_in | tongue_count | tongue_width_in | slit_width_in | root_midi | k_cantilever | stave_count | stave_miter_deg | end_config | port_diameter_in | tuning_trim_allowance_pct
DNT-HANDHELD | 6.000 | 9.000 | 0.375 | 5.250 | 8 | 1.000 | 0.125 | 72 | 24438 | 12 | 15.000 | solid | 2.000 | 5
DNT-MEDIUM-SEALED | 12.000 | 16.000 | 0.500 | 11.000 | 8 | 1.500 | 0.125 | 60 | 24438 | 12 | 15.000 | solid | 0.000 | 5
DNT-MEDIUM-PORTED | 12.000 | 16.000 | 0.500 | 11.000 | 8 | 1.500 | 0.125 | 60 | 24438 | 12 | 15.000 | one_port | 3.000 | 5
DNT-MEDIUM-DRUMHEAD | 12.000 | 16.000 | 0.500 | 11.000 | 8 | 1.500 | 0.125 | 60 | 24438 | 12 | 15.000 | drumhead | TBD | 5

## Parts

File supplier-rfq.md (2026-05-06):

# Supplier RFQ - Duntong Prototype Materials And Optional Hardware

Hello,

I am building a first prototype of an original wooden musical instrument called the duntong: a 12 in OD x 16 in long cylindrical tongue drum with optional sealed, ported, or drumhead ends.

Please quote the items below, including unit price, quantity price if available, lead time, shipping estimate, and any substitutions you recommend.

## Hardwood Stock

- Species: Padauk preferred; cherry or hard maple acceptable as alternate.
- Use: 12-stave cylindrical shell with tuned cantilever tongues.
- Rough need: 12 staves plus 2 spares, each about 16.5 in x 3.25 in x 1.10 in before surfacing.
- Grain: straight grain along the 16 in length.
- Requirements: stable, dry stock suitable for musical instrument work.

## Optional End Cap Stock

- Species: same as shell or visually compatible hardwood.
- Quantity: 2 blanks.
- Rough size: 13.25 in x 13.25 in x 0.80 in.
- Use: sealed or ported end caps.

## Optional Drumhead Hardware

- Shell OD: 12 in.
- Desired head type: goatskin/rawhide first choice; synthetic head acceptable as alternate.
- Please quote skin/head, rings/hoop, rope or hardware, and any recommended mounting parts.
- Use case: experimental hybrid dundun/tongue drum, hand-struck.

## CNC Tooling

- 1/8 in carbide upcut spiral router bit.
- Must be suitable for clean hardwood slit cutting.
- Please include shank diameter, flute length, recommended RPM/feed guidance if available.

## Substitution Rules

Do not substitute wood species without naming the species, density/modulus if known, and expected acoustic risk. Tongue pitch predictions depend on material stiffness-to-density ratio.

Thank you,

Tony Koop

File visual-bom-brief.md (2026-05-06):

# Visual BOM Brief

## Purpose

Create a one-page visual BOM for the DNT-MEDIUM duntong prototype in the style of Tony's Ashiko BOM reference: strong header, instrument image or drawing, itemized table, and concrete part visuals.

## Header

- Title: Duntong Original Cylindrical Tongue Drum - Medium Prototype
- Quote date: TBD when live sourcing is checked
- Estimated cost: TBD
- Assembly: DNT-MEDIUM stave-cylinder prototype

## Image Strategy

No built duntong photos exist yet. Use these placeholders honestly:

| Slot | Current asset | Replacement needed |
|---|---|---|
| Hero | `drawings/body-overview.svg` | Finished prototype photo |
| Tongue layout | `drawings/tongue-layout.svg` | CNC setup/process photo |
| End options | `drawings/end-config-options.svg` | Sealed, ported, and drumhead end photos |
| Fixture | `drawings/section-view.svg` | V-block cradle shop photo |

## BOM Rows

Show these grouped parts:

- Body: Padauk staves, end caps, optional port tube.
- Head option: goatskin/rawhide, rope/rings or synthetic hardware.
- CNC and fixtures: 1/8 in upcut bit, V-block cradle, wrap template.
- Support: rubber feet or cradle stand.
- Consumables: glue, abrasives, finish.

## Notes For Designer

- Label all generated drawings as engineering placeholders until replaced by real photos.
- Do not show live prices until `sourcing.csv` has date-checked supplier data.
- Include a footnote: "Original instrument concept by Tony Koop; first prototype measurements forthcoming."

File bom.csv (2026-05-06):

item_id | category | part_name | qty | unit | material_spec | dimensions | make_buy | source_or_supplier | search_terms | date_checked | unit_cost_usd | total_cost_usd | substitute_rule | drawing_ref | notes
B-001 | Body | Padauk staves | 12 | each | Padauk or alternate hardwood | 16 in x 3.1 in x 1.0 in rough | make | lumber supplier | padauk 4/4 or 5/4 lumber blank |  |  |  | Cherry or hard maple acceptable if K is updated | drawings/body-overview.svg | V1 medium stave shell
B-002 | Body | End cap blanks | 2 | each | Padauk or matching hardwood | 13 in x 13 in x 0.75 in | make | lumber supplier | padauk panel blank 13 inch square |  |  |  | Use drumhead hardware instead for Config D | drawings/end-config-options.svg | Sealed configuration baseline
B-003 | Body | Acoustic port tube | 1 | each | Wood or PVC | 3 in OD x 1 in length | make/buy | hardware supplier | 3 inch wood tube pvc pipe offcut |  |  |  | Only needed for ported variant | drawings/end-config-options.svg | Ported option
B-004 | Head | Goatskin rawhide | 1 | each | Goatskin or calfskin | 16 in or larger round | buy | drum parts supplier | goatskin drum head 16 inch rawhide |  |  |  | Synthetic head is alternate | drawings/end-config-options.svg | Optional true duntong end
B-005 | Head | Rope tuning kit | 1 | set | Low-stretch polyester or drum rope | TBD | buy | drum parts supplier | djembe rope tuning ring 12 inch |  |  |  | Only needed for goatskin variant | drawings/end-config-options.svg | Includes rings/pullers TBD
B-006 | CNC | 1/8 in upcut spiral bit | 1 | each | Carbide router bit | 0.125 in cutting diameter | buy | CNC tooling supplier | 1/8 upcut spiral router bit carbide |  |  |  | Must match CNC collet | drawings/tongue-layout.svg | Tongue slit cutter
B-007 | Fixture | V-block cradle | 1 | each | MDF or plywood fixture stock | for 12 in OD cylinder | make | shop stock | MDF plywood V block CNC cradle |  |  |  | Must include clamps and index marks | cnc/setup-sheet.md | Holds shell during tongue cutting
B-008 | Hardware | Rubber feet or cradle stand | 4 | each | Rubber bumper or hardwood cradle | TBD | buy/make | hardware supplier | rubber feet bumper instrument stand |  |  |  | Cradle preferred if cylinder wants to roll | drawings/body-overview.svg | Support for playing
B-009 | Consumable | Wood glue | 1 | bottle | Titebond III or equivalent | TBD | buy | hardware supplier | water resistant wood glue |  |  |  | Glue choice affects open time | assembly-manual.md | Stave shell glue-up
B-010 | Consumable | Finish and abrasives | 1 | set | Tung oil or lacquer plus 80-400 grit | TBD | buy | hardware supplier | tung oil instrument finish lacquer |  |  |  | Avoid heavy finish on active tongues | assembly-manual.md | Final finishing

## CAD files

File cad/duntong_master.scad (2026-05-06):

// Duntong parametric OpenSCAD starter
// Units: inches
// This is a concept/master-layout scaffold, not production CAM.

$fn = 96;

variant = "medium"; // "handheld" or "medium"
show_tongues = true;
show_end_caps = true;
show_vblock = false;

shell_od = variant == "handheld" ? 6 : 12;
shell_len = variant == "handheld" ? 9 : 16;
wall = variant == "handheld" ? 0.375 : 0.5;
shell_id = shell_od - 2 * wall;
tongue_count = 8;
tongue_width = variant == "handheld" ? 1.0 : 1.5;
slit_width = 0.125;
root_midi = variant == "handheld" ? 72 : 60;
k_cantilever = 24438;
trim_allowance = 1.05;
port_dia = variant == "handheld" ? 2.0 : 3.0;

notes = [
    ["C", 0],
    ["Eb", 3],
    ["F", 5],
    ["G", 7],
    ["Ab", 8],
    ["Bb", 10],
    ["C", 12],
    ["Eb", 15]
];

function freq_from_midi(m) = 440 * pow(2, (m - 69) / 12);
function tongue_len(offset) = sqrt(k_cantilever * wall / freq_from_midi(root_midi + offset)) * trim_allowance;

module shell() {
    difference() {
        cylinder(h = shell_len, d = shell_od, center = true);
        cylinder(h = shell_len + 0.1, d = shell_id, center = true);
    }
}

module tongue_cut(angle_deg, len, label) {
    // Visual placeholder only. Production geometry needs a wrapped or
    // projected sketch in SolidWorks.
    rotate([0, 0, angle_deg])
        translate([shell_od / 2 - wall / 2, 0, 0])
            rotate([0, 90, 0])
                union() {
                    cube([len, slit_width, wall * 3], center = true);
                    translate([len / 2, 0, 0])
                        cube([slit_width, tongue_width, wall * 3], center = true);
                    translate([-len / 2, 0, 0])
                        cube([slit_width, tongue_width, wall * 3], center = true);
                }
}

module tongue_labels() {
    for (i = [0 : tongue_count - 1]) {
        angle = i * 360 / tongue_count;
        len = tongue_len(notes[i][1]);
        rotate([0, 0, angle])
            translate([shell_od / 2 + 0.25, 0, 0])
                rotate([90, 0, angle])
                    linear_extrude(0.02)
                        text(str(notes[i][0], " ", len), size = 0.25, halign = "center");
    }
}

module end_caps() {
    translate([0, 0, shell_len / 2 + 0.02])
        cylinder(h = 0.35, d = shell_id, center = true);
    translate([0, 0, -shell_len / 2 - 0.02])
        cylinder(h = 0.35, d = shell_id, center = true);
}

module ported_end_cap() {
    difference() {
        cylinder(h = 0.35, d = shell_id, center = true);
        cylinder(h = 0.5, d = port_dia, center = true);
    }
}

module vblock() {
    translate([0, 0, -shell_od / 2 - 1.0])
        difference() {
            cube([shell_od + 4, shell_len + 3, 2], center = true);
            rotate([90, 0, 0])
                cylinder(h = shell_len + 4, d = shell_od + 0.25, center = true);
        }
}

difference() {
    shell();
    if (show_tongues) {
        for (i = [0 : tongue_count - 1]) {
            tongue_cut(i * 360 / tongue_count, tongue_len(notes[i][1]), notes[i][0]);
        }
    }
}

if (show_end_caps) {
    end_caps();
}

if (show_vblock) {
    vblock();
}

// Echo design table values for review.
echo(str("variant=", variant));
echo(str("shell_od=", shell_od, " shell_id=", shell_id, " length=", shell_len, " wall=", wall));
for (i = [0 : tongue_count - 1]) {
    echo(str(notes[i][0], " length_with_trim=", tongue_len(notes[i][1])));
}

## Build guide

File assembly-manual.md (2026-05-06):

# Duntong Assembly Manual

## Scope

This manual covers the DNT-MEDIUM V1 stave-cylinder prototype. It is not a CAM file and does not replace machine setup, feeds/speeds, or a SolidWorks drawing review.

## Tools

- Table saw with accurate miter sled.
- Jointer, planer, or drum sander.
- Band clamps or hose clamps for round glue-up.
- Wood lathe large enough for a 12 in OD shell.
- Drill press or lathe setup for port/end work.
- CNC router with 1/8 in upcut spiral bit, or hand-cut slit fallback.
- Calipers, flexible tape, tuner, microphone/recorder, hygrometer.
- Files, Dremel, sanding blocks, 80-400 grit abrasives.

## Phase 1 - Stock Prep

1. Confirm final V1 variant: sealed, ported, or drumheaded.
2. Select straight-grained Padauk or alternate hardwood. Record species, moisture content if available, and board orientation.
3. Rip at least 12 stave blanks plus 2 spares.
4. Cut 15 deg miters for a 12-stave cylinder.
5. Plane or sand all staves to a controlled thickness. Final shell wall is the tongue thickness, so record actual thickness at both ends of each stave.
6. Use one spare stave to cut scrap tongue coupons before cutting the real shell.

## Phase 2 - Shell Glue-Up

1. Dry-fit the 12 staves into a cylinder.
2. Glue as two half-shells if that improves clamping control.
3. Join half-shells into the full cylinder with band clamps.
4. Check roundness with calipers before the glue sets.
5. Let the shell cure fully before lathe work.

## Phase 3 - Turning And End Prep

1. Mount the shell on the lathe with support appropriate to the current blank.
2. True the outside to 12.000 in OD.
3. Bore or turn the inside to 11.000 in ID, leaving a 0.500 in wall.
4. Add end rabbets if sealed caps will be used.
5. For a ported cap, drill or turn the port after the cap is stable.
6. For a drumheaded end, leave enough rim/bearing-edge stock and do not drill hardware until the hardware package is selected.

## Phase 4 - Tongue Layout

1. Use `drawings/tongue-layout.svg` and the SolidWorks unwrap handoff as the layout basis.
2. Mark shell axis datum A, end planes B/C, equator plane D, and index zero E.
3. Print or laser a 1:1 wrap template once CAD is verified.
4. Place all eight tongues in a single ring around the equator for V1.
5. Start each tongue about 5 percent long so it tunes flat and can be shortened upward.

## Phase 5 - Tongue Cutting

1. Test the exact 1/8 in bit and slit depth on a scrap coupon.
2. Mount the shell in the V-block cradle.
3. Clamp so the final operation cannot release the shell.
4. Cut one tongue at a time.
5. Rotate the shell to the next index mark and re-check datum alignment.
6. Leave tabs or bridges only in non-vibrating areas if the CNC strategy requires them.
7. Deburr slits lightly without changing active tongue length.

## Phase 6 - Tuning

1. Measure every rough-cut tongue before trimming.
2. Tune from bass to treble.
3. To raise pitch, shorten at the tongue tip.
4. To lower pitch, thin near the tongue root with caution.
5. Record before/after Hz, temperature, humidity, and strike tool in `validation.csv`.
6. Stop when every note is within +/- 5 cents or when the remaining correction would risk structural damage.

## Phase 7 - End Configuration Tests

1. Test the sealed body first if solid caps are installed.
2. Test one-port response if the port cap is available.
3. Test the goatskin or synthetic head option only after the bearing edge and hardware are confirmed.
4. Record sustain, loudness, body resonance, and player feel for each configuration.

## Phase 8 - Finish And Support

1. Sand 80, 120, 180, 220, 320, and 400 grit as needed.
2. Avoid heavy finish on active tongue surfaces.
3. Apply 2-3 light coats of the selected finish on scrap first.
4. Add rubber feet or a cradle stand so the cylinder cannot roll during play.
5. Take process and finished photos listed in `photo-shotlist.md`.

## Maintenance

- Store away from extreme humidity swings.
- Re-check tuning after finish cure and after the first week of playing.
- If a tongue cracks, preserve the piece and log the failure mode before repair.

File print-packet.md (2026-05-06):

# Duntong Original Cylindrical Tongue Drum Print Packet

Generated: 2026-05-05
Packet folder: `/mnt/c/Users/Tony/Documents/GitHub/duntong`

## File Map

| File | Purpose |
| --- | --- |
| `design.md` | Project intent, catalog metadata, assumptions, and validation plan. |
| `bom.csv` | Starter bill of materials with part categories, quantities, drawing refs, and notes. |
| `sourcing.csv` | Supplier/search tracker with specs, price/date fields, lead time, substitutes, and risks. |
| `cut-list.csv` | Rough/final stock sizes, material, grain/orientation, operations, yield, and offcuts. |
| `drawing-brief.md` | Manufacturing drawing and technical product sketch brief. |
| `assembly-manual.md` | Shop-facing sequence, tools, fixtures, safety, tuning, finishing, and maintenance notes. |
| `validation.csv` | Target/measured values, tolerance, environment, result, and tuning/build action log. |
| `supplier-rfq.md` | Supplier email/request-for-quote starter. |
| `visual-bom-brief.md` | Art direction for an image-forward visual BOM. |
| `README.md` | Project artifact. |
| `family-spec.csv` | Project artifact. |
| `photo-shotlist.md` | Project artifact. |
| `risks.md` | Project artifact. |

## design.md

Project intent, catalog metadata, assumptions, and validation plan.

# Duntong Build Design

## Project Intent

The duntong is Tony Koop's original cylindrical tongue drum concept. It combines a dundun-like round body and optional drumhead/ported ends with wooden tongue drum voices cut directly into the shell wall.

The first build should answer three practical questions:

1. Can a cylindrical stave shell hold predictable cantilever tongue pitches?
2. Which end configuration gives the best musical balance: sealed, ported, or drumheaded?
3. Can the V1 be manufactured safely with Tony's available home-shop and Maker Nexus workflows before SolidWorks CAM exists?

Mode A repo shape is used here: this is a single-instrument repository, so files live at the repo root and in conventional folders.

## Design Intake

| Field | Value |
|---|---|
| Instrument ID | DNT-001 |
| Instrument type | Duntong |
| Family | Cylindrical tongue drum / drum-skin hybrid |
| Inventor | Tony Koop, 2026 |
| Workbook | `duntong-design-table.xlsx`, sheet `Duntong` |
| Reference workbook | `Musical Instruments V2.xlsx`, sheet `Duntong` |
| Done-bar reference | `tonykoop/tongue-drum` for tongue physics; `tonykoop/djembe`, `tonykoop/conga`, and `tonykoop/ashiko-drum-workshop` for segmented/stave construction |
| V1 recommendation | Medium stave cylinder, single-ring tongue layout, sealed or goatskin end option |
| Current scale baseline | C minor pentatonic from the workbook |
| Alternate scale request | D minor pentatonic remains TBD until the workbook row is updated |
| Primary material | Padauk in the workbook; cherry or maple alternate TBD |

Guided intake outputs are in `data/design-intake.json` and `data/design-input-row.csv`.

## Governing Model

### Tongues

The primary pitch model is a fixed-free cantilever beam:

```text
f = K * t / L^2
L = sqrt(K * t / f)
```

Where:

- `f` is tongue fundamental frequency in Hz.
- `K` is the material-specific imperial cantilever constant from the tongue-drum material library.
- `t` is the shell wall thickness in inches. This is also the tongue thickness.
- `L` is tongue length in inches.

For the workbook baseline, `K = 24438` for Padauk. The model assumes the tongue behaves like a flat cantilever. The workbook flags curvature as acceptable when tongue width divided by cylinder OD is less than or equal to 0.20. The handheld ratio is 1.0 / 6.0 = 0.167. The medium ratio is 1.5 / 12.0 = 0.125. Both are inside the first-pass range, but the curved shell may still raise pitch by about 2-5 percent and must be measured.

### Body And End Coupling

The cylinder body is secondary coupling, not the main pitch source. Four end conditions are preserved as design variants:

| Option | End condition | First-pass model | Musical character |
|---|---|---|---|
| A | Both ends solid | Helmholtz-like cavity using tongue slits as neck openings | Warm, focused sustain |
| B | One port, one solid | Stopped pipe approximation | Deeper bass projection |
| C | Two ports | Open pipe approximation | Brighter projection |
| D | One or both drumheads | Membrane plus cantilever hybrid | Closest to dundun inspiration |

Important guard rule: the NAF K2 bore correction does not apply to this instrument. Only cantilever beam K constants are used for tongue pitch. Helmholtz/stopped/open-pipe equations are exploration and validation targets for the body, not corrections to tongue length.

### Worked Medium Example

For the medium prototype:

```text
OD = 12.000 in
length = 16.000 in
wall/tongue thickness = 0.500 in
tongue width = 1.500 in
slit width = 0.125 in
K = 24438
root MIDI = 60 (C4)
```

The C4 tongue prediction is:

```text
L = sqrt(24438 * 0.5 / 261.63) = 6.834 in
```

The medium shell circumference is `pi * 12 = 37.699 in`, allowing about 23 tongue-width-plus-slit slots. The requested 8 tongues fit.

Using the workbook formula for sealed-body slit-area coupling:

```text
slit area = 8 * (0.125 * 1.5 + 2 * 0.125 * 3.0) = 7.5 in^2
internal volume = pi * (11 / 2)^2 * 16 = 1520.5 in^3
effective neck length = 0.5 in
f_H = 13552 / (2*pi) * sqrt(7.5 / (1520.5 * 0.5)) = about 214 Hz
```

The workbook prose note also mentions 135 Hz for medium sealed coupling. That appears to be a stale or alternate-geometry note; keep it visible as a validation question rather than treating either value as proven.

## Family / Variant Targets

| Variant | OD (in) | Length (in) | Wall (in) | Root | Tongues | Construction target |
|---|---:|---:|---:|---|---:|---|
| DNT-HANDHELD | 6.000 | 9.000 | 0.375 | C5 | 8 | Split-blank or stave prototype |
| DNT-MEDIUM | 12.000 | 16.000 | 0.500 | C4 | 8 | V1 stave cylinder |

Medium predicted tongue table:

| # | Note | MIDI | Target Hz | Predicted L (in) |
|---:|---|---:|---:|---:|
| 1 | C4 | 60 | 261.63 | 6.834 |
| 2 | Eb4 | 63 | 311.13 | 6.267 |
| 3 | F4 | 65 | 349.23 | 5.915 |
| 4 | G4 | 67 | 392.00 | 5.583 |
| 5 | Ab4 | 68 | 415.30 | 5.424 |
| 6 | Bb4 | 70 | 466.16 | 5.120 |
| 7 | C5 | 72 | 523.25 | 4.832 |
| 8 | Eb5 | 75 | 622.25 | 4.431 |

## Hardware Alignment

The V1 build is a stave-cylinder shell with CNC-cut tongue slits. The CNC plan is pre-CAM only; feeds, speeds, hold-down, and simulation must be set at the actual machine.

| Operation | Tooling | Fixture / datum | Notes |
|---|---|---|---|
| Rip staves | Table saw, miter sled | Long edge datum, 15 deg miter for 12 staves | Cut extra staves for tuning and destructive tests |
| Thickness staves | Planer / drum sander | Outside face A | Tongue pitch depends directly on final wall thickness |
| Glue cylinder | Band clamps or hose clamps | Shell axis datum A | Glue in two half-shells, then join halves |
| True shell | Lathe | Shell axis between centers/chuck | Final wall is tuning-critical |
| End cap or drumhead prep | Lathe, band saw, drill press | End plane datum B/C | Preserve sealed, ported, and drumhead variants |
| Tongue layout | 1:1 wrap template or SolidWorks unwrap | Shell axis A, equator plane D, index zero E | Single ring around equator for V1 |
| Tongue cuts | CNC router, 1/8 in upcut spiral | V-block cradle, rotary indexing, shell axis A | Start tongues about 5 percent long/flat for tuning trim |
| Tuning | Files, Dremel, tuner | Tongue root and tip marks | Shorten tip to raise pitch; thin near base to lower pitch |

## SolidWorks MasterLayout Plan

Do not fake SolidWorks files. This repo includes a real handoff:

- `cad/SolidWorks-MasterLayout-Plan.md`
- `cad/design-table-inputs.csv`
- `cad/sw-global-variables.csv`

The MasterLayout should own shell OD/ID/length, wall thickness, stave count, miter angle, tongue count, tongue lengths, slit width, tongue band position, end cap variant, port diameter, trim allowance, and registration datums. It should also include an unwrap or wrap-template drawing for V1 CNC layout.

## Open Assumptions

| Assumption | Status | Test |
|---|---|---|
| Padauk K = 24438 applies to curved shell tongues | First-order only | Measure struck pitch before and after slit tuning |
| Curvature ratio below 0.20 keeps flat-beam formula usable | First-order only | Compare predicted vs measured cents error on all eight tongues |
| Medium sealed-body coupling is near 214 Hz by current formula | Formula result | Verify against Excel cached value and measured cavity tap/impulse response |
| Workbook prose note of 135 Hz body resonance is stale or alternate geometry | TBD | Recalculate in Excel and Wolfram after dimensions are frozen |
| Single-ring layout is playable by one or two players | TBD | Mock hand reach on a 12 in diameter cylinder before CNC |
| Goatskin end option is the "true duntong" expression | Design intent | Build sealed, ported, and goatskin variants for comparison |

## Validation Plan

1. Build a scrap tongue coupon at the same wall thickness and grain orientation.
2. Cut one reference C4 tongue 5 percent long and tune upward to target.
3. Record before/after frequency, humidity, temperature, and material thickness.
4. Build the medium shell and cut the eight tongues from longest to shortest.
5. Measure every tongue after rough cut, after tuning, and after finish.
6. Test sealed, one-port, and goatskin end configurations with the same tongue set where practical.
7. Update `validation.csv` and feed measured data back through the empirical-learning loop once a prototype exists.

## bom.csv

Starter bill of materials with part categories, quantities, drawing refs, and notes.

| item_id | category | part_name | qty | unit | material_spec | dimensions | make_buy | source_or_supplier | search_terms | date_checked | unit_cost_usd | total_cost_usd | substitute_rule | drawing_ref | notes |
| --- | --- | --- | --- | --- | --- | --- | --- | --- | --- | --- | --- | --- | --- | --- | --- |
| B-001 | Body | Padauk staves | 12 | each | Padauk or alternate hardwood | 16 in x 3.1 in x 1.0 in rough | make | lumber supplier | padauk 4/4 or 5/4 lumber blank |  |  |  | Cherry or hard maple acceptable if K is updated | drawings/body-overview.svg | V1 medium stave shell |
| B-002 | Body | End cap blanks | 2 | each | Padauk or matching hardwood | 13 in x 13 in x 0.75 in | make | lumber supplier | padauk panel blank 13 inch square |  |  |  | Use drumhead hardware instead for Config D | drawings/end-config-options.svg | Sealed configuration baseline |
| B-003 | Body | Acoustic port tube | 1 | each | Wood or PVC | 3 in OD x 1 in length | make/buy | hardware supplier | 3 inch wood tube pvc pipe offcut |  |  |  | Only needed for ported variant | drawings/end-config-options.svg | Ported option |
| B-004 | Head | Goatskin rawhide | 1 | each | Goatskin or calfskin | 16 in or larger round | buy | drum parts supplier | goatskin drum head 16 inch rawhide |  |  |  | Synthetic head is alternate | drawings/end-config-options.svg | Optional true duntong end |
| B-005 | Head | Rope tuning kit | 1 | set | Low-stretch polyester or drum rope | TBD | buy | drum parts supplier | djembe rope tuning ring 12 inch |  |  |  | Only needed for goatskin variant | drawings/end-config-options.svg | Includes rings/pullers TBD |
| B-006 | CNC | 1/8 in upcut spiral bit | 1 | each | Carbide router bit | 0.125 in cutting diameter | buy | CNC tooling supplier | 1/8 upcut spiral router bit carbide |  |  |  | Must match CNC collet | drawings/tongue-layout.svg | Tongue slit cutter |
| B-007 | Fixture | V-block cradle | 1 | each | MDF or plywood fixture stock | for 12 in OD cylinder | make | shop stock | MDF plywood V block CNC cradle |  |  |  | Must include clamps and index marks | cnc/setup-sheet.md | Holds shell during tongue cutting |
| B-008 | Hardware | Rubber feet or cradle stand | 4 | each | Rubber bumper or hardwood cradle | TBD | buy/make | hardware supplier | rubber feet bumper instrument stand |  |  |  | Cradle preferred if cylinder wants to roll | drawings/body-overview.svg | Support for playing |
| B-009 | Consumable | Wood glue | 1 | bottle | Titebond III or equivalent | TBD | buy | hardware supplier | water resistant wood glue |  |  |  | Glue choice affects open time | assembly-manual.md | Stave shell glue-up |
| B-010 | Consumable | Finish and abrasives | 1 | set | Tung oil or lacquer plus 80-400 grit | TBD | buy | hardware supplier | tung oil instrument finish lacquer |  |  |  | Avoid heavy finish on active tongues | assembly-manual.md | Final finishing |

## sourcing.csv

Supplier/search tracker with specs, price/date fields, lead time, substitutes, and risks.

| source_id | item_id | component | specification | required_match | supplier_candidate | search_terms | url | date_checked | unit_price_usd | minimum_order | lead_time | substitution_risk | notes |
| --- | --- | --- | --- | --- | --- | --- | --- | --- | --- | --- | --- | --- | --- |
| S-001 | B-001 | Padauk stave stock | Stable straight-grained hardwood, enough for 12 staves plus spares | species and grain direction | lumber supplier | padauk lumber 4/4 5/4 straight grain |  |  |  |  | Medium | If cherry/maple is used, update K constant and validation rows |  |
| S-002 | B-002 | End cap blanks | 13 in square hardwood panels, 0.75 in thick | dimensions | lumber supplier | padauk panel blank 13x13 3/4 |  |  |  |  | Low | Can be face-glued from narrower boards |  |
| S-003 | B-003 | Port tube | 3 in diameter tube, about 1 in neck length | diameter if ported | hardware supplier | 3 inch pvc pipe wood tube |  |  |  |  | Medium | Port material may affect finish look but not primary tongue tuning |  |
| S-004 | B-004 | Goatskin rawhide | 16 in or larger round skin for 12 in shell | size and condition | drum parts supplier | 16 inch goatskin rawhide drum head |  |  |  |  | Medium | Must be checked live before purchase |  |
| S-005 | B-005 | Rope tuning hardware | Rope, rings, pullers sized for 12 in shell | fit | drum parts supplier | djembe rope tuning ring 12 inch |  |  |  |  | High | Hardware geometry must be frozen before drilling or rim detailing |  |
| S-006 | B-006 | 1/8 in upcut bit | Carbide spiral bit, 0.125 in kerf, suitable stickout | diameter and shank | CNC tooling supplier | 1/8 inch carbide upcut spiral router bit |  |  |  |  | Medium | Bit deflection will affect slit width and tuning |  |
| S-007 | B-007 | V-block fixture stock | Flat MDF/plywood, clamps, registration/index hardware | fixture rigidity | shop stock | MDF CNC fixture V block clamps |  |  |  |  | Low | Make in shop from scrap if stock is flat |  |
| S-008 | B-008 | Rubber feet or cradle stand | Non-marring feet or hardwood support cradle | stability | hardware supplier | rubber feet instrument bumper cradle |  |  |  |  | Low | Cradle is safer for rolling cylinder |  |
| S-009 | B-009 | Wood glue | Water-resistant wood glue with enough open time | bond quality | hardware supplier | Titebond III wood glue |  |  |  |  | Low | Glue-line stability matters because tongues are cut across the shell |  |
| S-010 | B-010 | Finish system | Low-build oil or lacquer, compatible with struck wood | finish behavior | hardware supplier | tung oil instrument finish lacquer |  |  |  |  | Medium | Finish must be tested on scrap tongue coupon |  |

## cut-list.csv

Rough/final stock sizes, material, grain/orientation, operations, yield, and offcuts.

| cut_id | part_name | variant | qty | rough_dimensions_in | finished_dimensions_in | material | grain_orientation | operation | yield_or_offcut_plan | drawing_ref | notes |
| --- | --- | --- | --- | --- | --- | --- | --- | --- | --- | --- | --- |
| C-001 | Stave blanks | DNT-MEDIUM | 12 | 16.50 x 3.25 x 1.10 | 16.00 x 3.142 x 1.00 | Padauk | grain along cylinder length | rip mitered staves | cut 2 spare staves for tuning coupons | drawings/body-overview.svg | 15 deg miter for 12 staves |
| C-002 | End cap blanks | DNT-MEDIUM | 2 | 13.25 x 13.25 x 0.80 | disc to fit 11 in ID rabbet | Padauk or matching hardwood | stable face grain | cut/turn end caps | offcuts become port and tuning test coupons | drawings/end-config-options.svg | Skip or modify for drumhead option |
| C-003 | V-block cradle | DNT-MEDIUM | 1 | 20 x 16 x 0.75 panels | 12 in OD support cradle | MDF or plywood | n/a | CNC or table saw fixture | save fixture for future variants | cnc/setup-sheet.md | Include index marks every 45 deg |
| C-004 | Tongue wrap template | DNT-MEDIUM | 1 | sheet size TBD | 1:1 wrap, 37.699 in circumference x 16 in length | paper or laser-safe sheet | n/a | print/laser template | n/a | drawings/tongue-layout.svg | SolidWorks unwrap should replace this after CAD |
| C-005 | Port tube | DNT-MEDIUM | 1 | 3.25 OD x 1.25 | 3.00 OD x 1.00 | wood or PVC | n/a | trim and fit | only for ported variant | drawings/end-config-options.svg | Actual neck length must be measured |
| C-006 | Scrap tongue coupons | DNT-MEDIUM | 3 | 8.0 x 2.0 x 0.5 | varies by test | same stock as shell | grain along tongue length | CNC test slits | destructive tests allowed | validation.csv | Use before cutting shell |
| C-007 | Handheld body blank | DNT-HANDHELD | 1 | 10 x 7 x 7 | 6 OD x 9 length x 0.375 wall | Padauk/cherry/maple TBD | grain along tongue length | split-blank or stave build | TBD for later prototype | drawings/body-overview.svg | Not V1 unless Tony selects handheld first |

## drawing-brief.md

Manufacturing drawing and technical product sketch brief.

# Drawing Brief

## Drawing Set

The current SVG drawing set is review-grade and should be replaced or extended by SolidWorks drawings before cutting expensive stock.

| Drawing | Purpose |
|---|---|
| `drawings/body-overview.svg` | Overall medium and handheld envelopes, major datums, V1 build target |
| `drawings/tongue-layout.svg` | Single-ring tongue schedule, note order, tongue lengths, wrap-template concept |
| `drawings/end-config-options.svg` | Sealed, ported, open/open, and drumhead end variants |
| `drawings/section-view.svg` | Cross-section of stave shell, wall/tongue thickness, end cap, V-block fixture concept |

## Drawing Standards

Each drawing must preserve:

- Title block with instrument, part, units, revision, date, and source workbook.
- Datums: shell axis A, left end B, right end C, equator plane D, index zero E.
- Critical dimensions: OD, ID, length, wall/tongue thickness, tongue length, tongue width, slit width, port diameter, and end cap rabbet.
- Default tolerance block: +/- 0.005 in for tongue length/thickness, +/- 0.030 in for noncritical wood body features unless CAD says otherwise.
- Material notes: Padauk baseline, alternate species require K update.
- Operation notes: no G-code; V-block or rotary indexing required for cylindrical tongue cuts.

## CAD Handoff

SolidWorks should create:

1. MasterLayout part with global variables from `cad/sw-global-variables.csv`.
2. Configuration table for handheld and medium variants.
3. Cylindrical unwrap sketch for the single-ring tongue layout.
4. Optional end-cap configurations: sealed, ported, drumhead.
5. Drawing sheets exported to PDF/SVG before CAM.

## assembly-manual.md

Shop-facing sequence, tools, fixtures, safety, tuning, finishing, and maintenance notes.

# Duntong Assembly Manual

## Scope

This manual covers the DNT-MEDIUM V1 stave-cylinder prototype. It is not a CAM file and does not replace machine setup, feeds/speeds, or a SolidWorks drawing review.

## Tools

- Table saw with accurate miter sled.
- Jointer, planer, or drum sander.
- Band clamps or hose clamps for round glue-up.
- Wood lathe large enough for a 12 in OD shell.
- Drill press or lathe setup for port/end work.
- CNC router with 1/8 in upcut spiral bit, or hand-cut slit fallback.
- Calipers, flexible tape, tuner, microphone/recorder, hygrometer.
- Files, Dremel, sanding blocks, 80-400 grit abrasives.

## Phase 1 - Stock Prep

1. Confirm final V1 variant: sealed, ported, or drumheaded.
2. Select straight-grained Padauk or alternate hardwood. Record species, moisture content if available, and board orientation.
3. Rip at least 12 stave blanks plus 2 spares.
4. Cut 15 deg miters for a 12-stave cylinder.
5. Plane or sand all staves to a controlled thickness. Final shell wall is the tongue thickness, so record actual thickness at both ends of each stave.
6. Use one spare stave to cut scrap tongue coupons before cutting the real shell.

## Phase 2 - Shell Glue-Up

1. Dry-fit the 12 staves into a cylinder.
2. Glue as two half-shells if that improves clamping control.
3. Join half-shells into the full cylinder with band clamps.
4. Check roundness with calipers before the glue sets.
5. Let the shell cure fully before lathe work.

## Phase 3 - Turning And End Prep

1. Mount the shell on the lathe with support appropriate to the current blank.
2. True the outside to 12.000 in OD.
3. Bore or turn the inside to 11.000 in ID, leaving a 0.500 in wall.
4. Add end rabbets if sealed caps will be used.
5. For a ported cap, drill or turn the port after the cap is stable.
6. For a drumheaded end, leave enough rim/bearing-edge stock and do not drill hardware until the hardware package is selected.

## Phase 4 - Tongue Layout

1. Use `drawings/tongue-layout.svg` and the SolidWorks unwrap handoff as the layout basis.
2. Mark shell axis datum A, end planes B/C, equator plane D, and index zero E.
3. Print or laser a 1:1 wrap template once CAD is verified.
4. Place all eight tongues in a single ring around the equator for V1.
5. Start each tongue about 5 percent long so it tunes flat and can be shortened upward.

## Phase 5 - Tongue Cutting

1. Test the exact 1/8 in bit and slit depth on a scrap coupon.
2. Mount the shell in the V-block cradle.
3. Clamp so the final operation cannot release the shell.
4. Cut one tongue at a time.
5. Rotate the shell to the next index mark and re-check datum alignment.
6. Leave tabs or bridges only in non-vibrating areas if the CNC strategy requires them.
7. Deburr slits lightly without changing active tongue length.

## Phase 6 - Tuning

1. Measure every rough-cut tongue before trimming.
2. Tune from bass to treble.
3. To raise pitch, shorten at the tongue tip.
4. To lower pitch, thin near the tongue root with caution.
5. Record before/after Hz, temperature, humidity, and strike tool in `validation.csv`.
6. Stop when every note is within +/- 5 cents or when the remaining correction would risk structural damage.

## Phase 7 - End Configuration Tests

1. Test the sealed body first if solid caps are installed.
2. Test one-port response if the port cap is available.
3. Test the goatskin or synthetic head option only after the bearing edge and hardware are confirmed.
4. Record sustain, loudness, body resonance, and player feel for each configuration.

## Phase 8 - Finish And Support

1. Sand 80, 120, 180, 220, 320, and 400 grit as needed.
2. Avoid heavy finish on active tongue surfaces.
3. Apply 2-3 light coats of the selected finish on scrap first.
4. Add rubber feet or a cradle stand so the cylinder cannot roll during play.
5. Take process and finished photos listed in `photo-shotlist.md`.

## Maintenance

- Store away from extreme humidity swings.
- Re-check tuning after finish cure and after the first week of playing.
- If a tongue cracks, preserve the piece and log the failure mode before repair.

## validation.csv

Target/measured values, tolerance, environment, result, and tuning/build action log.

| measurement_id | variant | note | midi | target_hz | predicted_length_in | measured_hz | cents_error | tolerance_cents | environment | result | action |
| --- | --- | --- | --- | --- | --- | --- | --- | --- | --- | --- | --- |
| V-001 | DNT-MEDIUM | C4 | 60 | 261.63 | 6.834 |  |  | 5 | TBD | pending | Measure scrap C4 tongue before shell cut |
| V-002 | DNT-MEDIUM | Eb4 | 63 | 311.13 | 6.267 |  |  | 5 | TBD | pending | Measure after rough cut and after tuning |
| V-003 | DNT-MEDIUM | F4 | 65 | 349.23 | 5.915 |  |  | 5 | TBD | pending | Measure after rough cut and after tuning |
| V-004 | DNT-MEDIUM | G4 | 67 | 392.00 | 5.583 |  |  | 5 | TBD | pending | Measure after rough cut and after tuning |
| V-005 | DNT-MEDIUM | Ab4 | 68 | 415.30 | 5.424 |  |  | 5 | TBD | pending | Measure after rough cut and after tuning |
| V-006 | DNT-MEDIUM | Bb4 | 70 | 466.16 | 5.120 |  |  | 5 | TBD | pending | Measure after rough cut and after tuning |
| V-007 | DNT-MEDIUM | C5 | 72 | 523.25 | 4.832 |  |  | 5 | TBD | pending | Measure after rough cut and after tuning |
| V-008 | DNT-MEDIUM | Eb5 | 75 | 622.25 | 4.431 |  |  | 5 | TBD | pending | Measure after rough cut and after tuning |
| V-009 | DNT-MEDIUM | sealed-body-formula |  | 214.23 |  |  |  | 20 | TBD | pending | Verify against Excel and impulse response |
| V-010 | DNT-MEDIUM | stopped-pipe-one-port |  | 211.75 |  |  |  | 20 | TBD | pending | Test one-port body response if Config B is built |
| V-011 | DNT-MEDIUM | open-pipe-two-port |  | 423.50 |  |  |  | 20 | TBD | pending | Test two-port body response if Config C is built |
| V-012 | DNT-MEDIUM | drumhead-body-response |  |  |  |  |  | 20 | TBD | pending | Record membrane tuning and coupled tone if Config D is built |

## supplier-rfq.md

Supplier email/request-for-quote starter.

# Supplier RFQ - Duntong Prototype Materials And Optional Hardware

Hello,

I am building a first prototype of an original wooden musical instrument called the duntong: a 12 in OD x 16 in long cylindrical tongue drum with optional sealed, ported, or drumhead ends.

Please quote the items below, including unit price, quantity price if available, lead time, shipping estimate, and any substitutions you recommend.

## Hardwood Stock

- Species: Padauk preferred; cherry or hard maple acceptable as alternate.
- Use: 12-stave cylindrical shell with tuned cantilever tongues.
- Rough need: 12 staves plus 2 spares, each about 16.5 in x 3.25 in x 1.10 in before surfacing.
- Grain: straight grain along the 16 in length.
- Requirements: stable, dry stock suitable for musical instrument work.

## Optional End Cap Stock

- Species: same as shell or visually compatible hardwood.
- Quantity: 2 blanks.
- Rough size: 13.25 in x 13.25 in x 0.80 in.
- Use: sealed or ported end caps.

## Optional Drumhead Hardware

- Shell OD: 12 in.
- Desired head type: goatskin/rawhide first choice; synthetic head acceptable as alternate.
- Please quote skin/head, rings/hoop, rope or hardware, and any recommended mounting parts.
- Use case: experimental hybrid dundun/tongue drum, hand-struck.

## CNC Tooling

- 1/8 in carbide upcut spiral router bit.
- Must be suitable for clean hardwood slit cutting.
- Please include shank diameter, flute length, recommended RPM/feed guidance if available.

## Substitution Rules

Do not substitute wood species without naming the species, density/modulus if known, and expected acoustic risk. Tongue pitch predictions depend on material stiffness-to-density ratio.

Thank you,

Tony Koop

## visual-bom-brief.md

Art direction for an image-forward visual BOM.

# Visual BOM Brief

## Purpose

Create a one-page visual BOM for the DNT-MEDIUM duntong prototype in the style of Tony's Ashiko BOM reference: strong header, instrument image or drawing, itemized table, and concrete part visuals.

## Header

- Title: Duntong Original Cylindrical Tongue Drum - Medium Prototype
- Quote date: TBD when live sourcing is checked
- Estimated cost: TBD
- Assembly: DNT-MEDIUM stave-cylinder prototype

## Image Strategy

No built duntong photos exist yet. Use these placeholders honestly:

| Slot | Current asset | Replacement needed |
|---|---|---|
| Hero | `drawings/body-overview.svg` | Finished prototype photo |
| Tongue layout | `drawings/tongue-layout.svg` | CNC setup/process photo |
| End options | `drawings/end-config-options.svg` | Sealed, ported, and drumhead end photos |
| Fixture | `drawings/section-view.svg` | V-block cradle shop photo |

## BOM Rows

Show these grouped parts:

- Body: Padauk staves, end caps, optional port tube.
- Head option: goatskin/rawhide, rope/rings or synthetic hardware.
- CNC and fixtures: 1/8 in upcut bit, V-block cradle, wrap template.
- Support: rubber feet or cradle stand.
- Consumables: glue, abrasives, finish.

## Notes For Designer

- Label all generated drawings as engineering placeholders until replaced by real photos.
- Do not show live prices until `sourcing.csv` has date-checked supplier data.
- Include a footnote: "Original instrument concept by Tony Koop; first prototype measurements forthcoming."

## README.md

Project artifact.

# Duntong - Original Cylindrical Tongue Drum

> Tony Koop's original hybrid instrument concept: a dundun-inspired cylindrical drum body with tuned wooden tongue-drum voices cut around the shell.

## What This Is

The duntong is an original instrument design by Tony Koop. It combines the social, cylindrical playing form of a hand drum with the melodic tuning logic of a wooden tongue drum. Instead of cutting tongues into a flat box lid, the duntong places cantilever tongues around a round shell so the instrument can be played from multiple sides.

The current design table defines two prototype sizes:

1. **Handheld:** 6 in OD x 9 in long, C5-root pentatonic minor, 0.375 in tongue wall.
2. **Medium:** 12 in OD x 16 in long, C4-root pentatonic minor, 0.5 in tongue wall.

The V1 build target is the medium stave-cylinder prototype with a single ring of eight tongues around the equator. The workbook also preserves sealed, ported, and drumhead end variants so the instrument can be tested as a melodic tongue drum, a resonant ported body, and a true dundun/tongue hybrid.

## Why It Is Interesting

Most wooden tongue drums are rectangular boxes. Most dunduns are membrane drums. The duntong asks a neat acoustics question: can a round wooden drum body carry tuned cantilever tongues while still behaving like a hand-drum shell?

The current model treats the tongues as fixed-free cantilever beams:

```text
f = K * t / L^2
```

The cylinder cavity is treated as secondary coupling, not as the main pitch source. The first prototype should measure how much the curved wall, stave glue lines, end condition, and cavity resonance shift the tongue predictions.

## Repository Map

```text
duntong/
├── README.md
├── design.md
├── duntong-design-table.xlsx
├── family-spec.csv
├── bom.csv
├── sourcing.csv
├── cut-list.csv
├── validation.csv
├── assembly-manual.md
├── supplier-rfq.md
├── visual-bom-brief.md
├── drawing-brief.md
├── risks.md
├── photo-shotlist.md
├── cad/
├── cnc/
├── data/
├── drawings/
├── images/
├── site/
└── wolfram/
```

## Current Status

| Area | Status |
|---|---|
| Original concept and workbook | Done |
| Guided v4.2 intake | Done |
| Build packet docs | Drafted for V1 review |
| Drawings | SVG review drawings included |
| CNC/CAM | Pre-CAM operation plan only; no G-code |
| SolidWorks | MasterLayout handoff files included; no fake CAD |
| Wolfram | Readable `.wl` source included |
| Prototype data | Forthcoming |

## Sister Repos

- [tongue-drum](https://github.com/tonykoop/tongue-drum) for cantilever tongue physics and the DoE tuning pattern.
- [dundun](https://github.com/tonykoop/dundun) for the drum-family inspiration.
- [djembe](https://github.com/tonykoop/djembe) and [ashiko-drum-workshop](https://github.com/tonykoop/ashiko-drum-workshop) for segmented/stave drum construction references.

## License

[CC BY 4.0](LICENSE) - see LICENSE for details.

## family-spec.csv

Project artifact.

| member_id | target_hz | target_note | scale_label | predicted_length_in | predicted_width_in | predicted_height_in | predicted_volume_cuin | wood_species | k_constant | k2_correction | outer_diameter_in | inner_diameter_in | wall_thickness_in | tongue_count | slit_width_in | construction_method | notes |
| --- | --- | --- | --- | --- | --- | --- | --- | --- | --- | --- | --- | --- | --- | --- | --- | --- | --- |
| DNT-HANDHELD | 523.25 | C5 | C minor pentatonic | 9.000 | 6.000 | 6.000 | 194.83 | Padauk | 24438 | 0 | 6.000 | 5.250 | 0.375 | 8 | 0.125 | split-blank or stave | Handheld proof of concept; workbook root MIDI 72 |
| DNT-MEDIUM | 261.63 | C4 | C minor pentatonic | 16.000 | 12.000 | 12.000 | 1520.53 | Padauk | 24438 | 0 | 12.000 | 11.000 | 0.500 | 8 | 0.125 | stave cylinder | V1 build target; medium floor/table instrument |

## photo-shotlist.md

Project artifact.

# Photo Shotlist

This follows `instrument-maker/docs/photo-pipeline.md`. No owned duntong hero photo exists yet, so the README and site should say photos forthcoming rather than link broken images.

## File Naming

Use:

```text
images/00-hero-duntong-medium-finished.jpg
images/01-workbook-design-table.jpg
images/02-stave-stock-layout.jpg
images/03-stave-glue-up.jpg
images/04-turned-cylinder-shell.jpg
images/05-wrap-template-on-shell.jpg
images/06-vblock-cnc-setup.jpg
images/07-tongue-slit-cutting.jpg
images/08-tuning-with-tuner.jpg
images/09-end-config-comparison.jpg
images/10-finished-detail.jpg
```

## Required Shots

| Shot | Purpose | Status |
|---|---|---|
| Hero finished instrument | README/site hero | Forthcoming |
| Workbook/source table | Shows parametric design source | Forthcoming |
| Stave stock | Documents grain and material | Forthcoming |
| Stave glue-up | Shows cylindrical shell construction | Forthcoming |
| Lathe turning | Shows wall thickness control | Forthcoming |
| Wrap template | Shows cylindrical tongue layout | Forthcoming |
| V-block CNC setup | Shows safe workholding | Forthcoming |
| Tongue cutting | Shows slit operation | Forthcoming |
| Tuning | Shows validation method | Forthcoming |
| End variants | Sealed/ported/drumheaded comparison | Forthcoming |

## Rules

- Use owned photos when available.
- If generated concept images are added, label them as generated placeholders.
- Replace generated or drawing placeholders with process photos after the first prototype.
- Do not use absolute local paths in README or `site/index.html`.

## risks.md

Project artifact.

# Duntong Risks

## Acoustic

### Acoustic Tongues ring sharp from curvature

**Symptom:** The rough-cut tongues measure consistently sharp compared with the flat cantilever prediction.

**Mechanism:** The shell is curved, not flat. Even with a width/OD ratio below 0.20, curvature and stave glue lines may stiffen the tongue relative to the workbook model.

**Test:** Cut a scrap coupon and one shell test tongue 5 percent long. Record predicted vs measured Hz before final shell cutting.

**Mitigation:** Add a measured curvature correction to the design table, leave more tuning allowance, or lower the starting root for V1.

**Severity:** Medium.

## Structural

### Structural Stave glue lines weaken active tongue zones

**Symptom:** A tongue cracks, buzzes, or loses sustain along a glue line after cutting or playing.

**Mechanism:** Stave construction creates glue lines around the circumference. If a tongue crosses or terminates near a glue line, the local boundary condition may be weak or damped.

**Test:** Align the wrap template against stave seams before cutting. Strike-test a tongue coupon that includes a glue line.

**Mitigation:** Place tongue centerlines between stave seams, widen non-vibrating bridges, or switch the V1 to split-blank construction for the handheld proof.

**Severity:** High; human decision required before cutting if the final tongue layout crosses seams.

## Ergonomic

### Ergonomic Cylinder rolls or forces awkward wrist angle

**Symptom:** Player has to stabilize the instrument instead of playing, or wrist extension becomes uncomfortable on the far-side tongues.

**Mechanism:** A 12 in round shell on a table can roll unless supported. A full 360-degree note layout may invite reaches around the cylinder.

**Test:** Mock the 12 in OD shell with a tube or cardboard form. Mark eight note positions and test seated/table/floor playing positions.

**Mitigation:** Add rubber feet, a cradle stand, or rotate the note order to keep common patterns near the player.

**Severity:** Medium.

## Supply

### Supply Tonewood substitution changes K constant

**Symptom:** Tongues cut to Padauk lengths do not tune correctly when cherry, maple, or another hardwood is substituted.

**Mechanism:** The cantilever formula depends on the material K constant. Species changes alter stiffness-to-density ratio.

**Test:** Before substituting, update `K` in the workbook and cut a coupon from the actual stock.

**Mitigation:** Keep Padauk for V1 or make species substitution an explicit DoE factor with separate validation rows.

**Severity:** Medium.

## Fit/Finish

### Fit/Finish Finish buildup damps tongues

**Symptom:** Tuned tongues lose sustain or shift pitch after finishing.

**Mechanism:** Oil, lacquer, or film finish adds mass and damping to the active tongue surface and slit walls.

**Test:** Finish a tuned coupon with the planned schedule and measure before/after Hz, sustain, and cents error.

**Mitigation:** Use a low-build finish, mask active tongue surfaces, or tune after the finish has cured.

**Severity:** Medium.

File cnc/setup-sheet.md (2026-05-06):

# CNC / Manufacturing Setup Sheet

- Packet: `.`
- Family: duntong-hybrid
- Generated: 2026-05-06
- Machine note: Pre-CAM plan for a stave-shell cylindrical tongue drum. Verify actual CNC router, lathe swing, clamps, feed/speed, bit stickout, and air-cut before machining.

## Assumptions

- This is not G-code.
- V1 target is the medium 12 in OD x 16 in long stave-cylinder prototype.
- Tongue pitches depend on final wall thickness, so stock prep and turning checks are tuning-critical.
- The CNC tongue operation needs either a rigid V-block with rotary indexing or a true rotary axis.

## Operation Graph

### OP-010 - Review workbook, drawings, and datums

- Machine: Bench
- Tool: Calipers, flexible tape, square, marker
- Workholding: Flat bench
- Datum: Shell axis A, left end B, right end C, equator D, index zero E
- Inputs: `design.md`, `drawing-brief.md`, `family-spec.csv`
- Outputs: marked datum checklist
- Checks:
  - C minor vs D minor decision visible
  - End configuration selected or marked TBD
  - No CAM until SolidWorks unwrap is reviewed
- Notes: Preserve all TBDs instead of burying them in CAM assumptions.

### OP-110 - Cut and thickness stave blanks

- Machine: Table saw, jointer, planer, drum sander
- Tool: Sharp rip/crosscut blade, planer knives, calipers
- Workholding: Miter sled, featherboard, push blocks
- Datum: Outside face and long edge of each stave
- Inputs: `cut-list.csv`, `bom.csv`
- Outputs: 12 staves plus spare coupons
- Checks:
  - 15 deg miter verified on scrap
  - Thickness recorded for every stave
  - Straight grain along shell length
- Notes: Cut extra stock for destructive tongue and finish tests.

### OP-210 - Glue stave cylinder

- Machine: Bench
- Tool: Band clamps, hose clamps, cauls, glue brush
- Workholding: Round clamp-up with two-half-shell option
- Datum: Shell axis A established by roundness checks
- Inputs: `assembly-manual.md`
- Outputs: cured cylindrical shell blank
- Checks:
  - Glue gaps inspected
  - Roundness checked before cure
  - Seam positions logged for tongue layout
- Notes: Tongue roots should avoid weak seam locations where possible.

### OP-310 - Turn shell to OD, ID, and wall thickness

- Machine: Wood lathe
- Tool: Bowl gouge, scraper, calipers, wall-thickness gauge
- Workholding: Chuck/faceplate with tailstock support as appropriate
- Datum: Shell axis A
- Inputs: `drawings/section-view.svg`
- Outputs: 12 in OD, 11 in ID, 0.5 in wall shell
- Checks:
  - Wall thickness within tuning tolerance
  - Ends square to axis
  - No thin spots below 0.5 in before tongue cuts
- Notes: Final wall is the tongue thickness in `f = K*t/L^2`.

### OP-410 - Prepare end configuration

- Machine: Lathe, drill press, band saw, bench
- Tool: Forstner bits, hole saw, turning tools, sanding blocks
- Workholding: End-cap fixture or rim support
- Datum: End planes B and C
- Inputs: `drawings/end-config-options.svg`, `bom.csv`
- Outputs: sealed caps, ported cap, or drumhead-ready rim
- Checks:
  - Port diameter and neck length measured if ported
  - Bearing edge smooth if drumheaded
  - Cap fit tested before glue
- Notes: Do not drill hardware for drumhead until the actual hardware is sourced.

### OP-510 - Create wrap template and index plan

- Machine: Laser cutter, printer, or SolidWorks drawing export
- Tool: Paper template, laser-safe sheet, marking knife
- Workholding: Template taped to shell with index zero
- Datum: Equator plane D and index zero E
- Inputs: `drawings/tongue-layout.svg`, `cad/design-table-inputs.csv`
- Outputs: 1:1 tongue wrap template
- Checks:
  - Circumference is 37.699 in for medium
  - Eight index steps at 45 deg
  - Tongue lengths include tuning trim allowance
- Notes: SolidWorks unwrap should replace the temporary SVG-derived template.

### OP-610 - CNC cut tongue slits

- Machine: CNC router
- Tool: 1/8 in upcut spiral bit
- Workholding: Rigid V-block cradle, clamps clear of toolpath, rotary index marks
- Datum: Shell axis A, equator D, index zero E
- Inputs: `cad/SolidWorks-MasterLayout-Plan.md`, `drawings/tongue-layout.svg`
- Outputs: rough-cut eight-tongue shell
- Checks:
  - Air-cut complete
  - Bit deflection checked on coupon
  - Shell cannot rotate/slip during final cut
  - No tongue crosses a weak seam without approval
- Notes: Cut one tongue, re-index, re-clamp, and verify before the next cut unless a true rotary axis is used.

### OP-710 - Tune tongues and validate body coupling

- Machine: Bench
- Tool: Chromatic tuner, microphone, file, Dremel, sanding block
- Workholding: Padded cradle or stand
- Datum: Tongue root and tip marks
- Inputs: `validation.csv`
- Outputs: updated validation.csv, measured tuning notes
- Checks:
  - Every tongue has measured Hz
  - Cents error computed
  - End configuration response logged
  - Finish shift measured after cure
- Notes: Shorten tongue tip to raise pitch. Thin near root only with caution.

## Release Checks

- [ ] Every operation has a datum and workholding method.
- [ ] CNC operations have a fixture and clamp plan.
- [ ] All tuning-critical dimensions include measurement checkpoints.
- [ ] No file claims to be verified CAM or G-code.
- [ ] `validation.csv` is updated after prototype measurements.

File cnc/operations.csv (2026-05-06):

op_id | name | machine | tool | workholding | datum | inputs | outputs | checks | notes
OP-010 | Review workbook, drawings, and datums | Bench | Calipers, flexible tape, square, marker | Flat bench | Shell axis A; left end B; right end C; equator D; index zero E | design.md; drawing-brief.md; family-spec.csv | marked datum checklist | C minor vs D minor decision visible; end configuration selected or marked TBD; no CAM until SolidWorks unwrap is reviewed | Preserve all TBDs instead of burying them in CAM assumptions.
OP-110 | Cut and thickness stave blanks | Table saw, jointer, planer, drum sander | Sharp rip/crosscut blade, planer knives, calipers | Miter sled, featherboard, push blocks | Outside face and long edge of each stave | cut-list.csv; bom.csv | 12 staves plus spare coupons | 15 deg miter verified on scrap; thickness recorded for every stave; straight grain along shell length | Cut extra stock for destructive tongue and finish tests.
OP-210 | Glue stave cylinder | Bench | Band clamps, hose clamps, cauls, glue brush | Round clamp-up with two-half-shell option | Shell axis A established by roundness checks | assembly-manual.md | cured cylindrical shell blank | Glue gaps inspected; roundness checked before cure; seam positions logged for tongue layout | Tongue roots should avoid weak seam locations where possible.
OP-310 | Turn shell to OD, ID, and wall thickness | Wood lathe | Bowl gouge, scraper, calipers, wall-thickness gauge | Chuck/faceplate with tailstock support | Shell axis A | drawings/section-view.svg | 12 in OD, 11 in ID, 0.5 in wall shell | Wall thickness within tuning tolerance; ends square to axis; no thin spots below 0.5 in before tongue cuts | Final wall is the tongue thickness in f = K*t/L^2.
OP-410 | Prepare end configuration | Lathe, drill press, band saw, bench | Forstner bits, hole saw, turning tools, sanding blocks | End-cap fixture or rim support | End planes B and C | drawings/end-config-options.svg; bom.csv | sealed caps, ported cap, or drumhead-ready rim | Port diameter and neck length measured if ported; bearing edge smooth if drumheaded; cap fit tested before glue | Do not drill hardware for drumhead until the actual hardware is sourced.
OP-510 | Create wrap template and index plan | Laser cutter, printer, or SolidWorks drawing export | Paper template, laser-safe sheet, marking knife | Template taped to shell with index zero | Equator plane D and index zero E | drawings/tongue-layout.svg; cad/design-table-inputs.csv | 1:1 tongue wrap template | Circumference is 37.699 in for medium; eight index steps at 45 deg; tongue lengths include tuning trim allowance | SolidWorks unwrap should replace the temporary SVG-derived template.
OP-610 | CNC cut tongue slits | CNC router | 1/8 in upcut spiral bit | Rigid V-block cradle, clamps clear of toolpath, rotary index marks | Shell axis A, equator D, index zero E | cad/SolidWorks-MasterLayout-Plan.md; drawings/tongue-layout.svg | rough-cut eight-tongue shell | Air-cut complete; bit deflection checked on coupon; shell cannot rotate/slip during final cut; no tongue crosses a weak seam without approval | Cut one tongue, re-index, re-clamp, and verify before the next cut unless a true rotary axis is used.
OP-710 | Tune tongues and validate body coupling | Bench | Chromatic tuner, microphone, file, Dremel, sanding block | Padded cradle or stand | Tongue root and tip marks | validation.csv | updated validation.csv; measured tuning notes | Every tongue has measured Hz; cents error computed; end configuration response logged; finish shift measured after cure | Shorten tongue tip to raise pitch. Thin near root only with caution.

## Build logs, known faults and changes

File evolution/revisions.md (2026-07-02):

# Revision Register — duntong

| Rev | Date | Parent | Delta | Downstream artifacts invalidated |
| --- | --- | --- | --- | --- |
| A | 2026-07-01 | — | Stage 0 intake of current masters (cad/duntong_master.scad + duntong-design-table.xlsx). | none (no alpha/beta/production artifacts exist yet) |

Stage 0 only. Gate A has not been run; no Alpha compiles, vendor quotes, or production lock exist for this product.

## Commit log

2026-05-02 Initial scaffold: Duntong
    [duntong-design-table.xlsx]
2026-05-06 update v4
    [bom.csv, cut-list.csv, design-input-row.csv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]
2026-05-18 Add conservative V5 explorer packet (#2)
    [family-spec.csv, visual-output-register.csv]
2026-05-31 Add image-gen concept prompt; wire explorer images
2026-05-31 Add deployable Wolfram interactive model + wire live explorer embed
    Model returns a bare Manipulate (SaveDefinitions->True); CloudDeploy'd Public.
2026-06-23 feat(wolfram): deploy interactive model + live explorer embed (#7)
    * feat(v5): upgrade explorer to V5 format + fill build-packet gaps
    - Replace explorer.html with V5 parchment card format: readiness chip,
    authority-split chip, family chip, per-artifact authority badges
    (fabrication / derived_preview / reference_only / source_only)
    - Add data/deliverables-export.json machine-readable manifest
    - Add any missing build-packet stubs (drawing-brief.md, assembly-manual.md,
    supplier-rfq.md, visual-bom-brief.md, photo-shotlist.md, sourcing.csv,
    cut-list.csv, cnc/setup-sheet.md) as TBD-ready placeholders
    Refs instrument-maker v4.5 · tonykoop/duntong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
2026-07-02 V5 packet refresh: status line, provenance, parametric OpenSCAD master, evolution intake
    - README: added parseable **Status:** L2 V5 build-packet candidate line
    (repo already carried the full L2 surface: design.md, bom/sourcing/cut-list/
    validation.csv, risks.md, drawing-brief.md, visual-output-register.csv,
    cad/mcp-session-log.md); added evolution/ to repo map and status table.
    - cad/duntong_master.scad kept exactly as-is (existing parametric master,
    EXISTING MASTERS clause); render check: `openscad -o /tmp/duntong-check.stl
    cad/duntong_master.scad` exit 0.
    - wolfram/duntong-wolfram-model.wl already present and correctly named; added
    visual-output-register.csv row (WL-001, deriv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
    [visual-output-register.csv]
